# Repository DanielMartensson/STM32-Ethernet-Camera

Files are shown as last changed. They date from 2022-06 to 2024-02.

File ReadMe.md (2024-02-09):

# STM32 Ethernet camera

This project have:

 * CAN-bus
 * Encoder
 * Input capture
 * DAC 12-bit
 * ADC 12-bit
 * Digital N-channel output
 * Digital input
 * FSCM 16-Bit LCD
 * DCMI camera
 * Ethernet

This project will focus on

 * OV7670 Camera SCCB protocol for computer vision
 * Ethernet for STM32F4 series

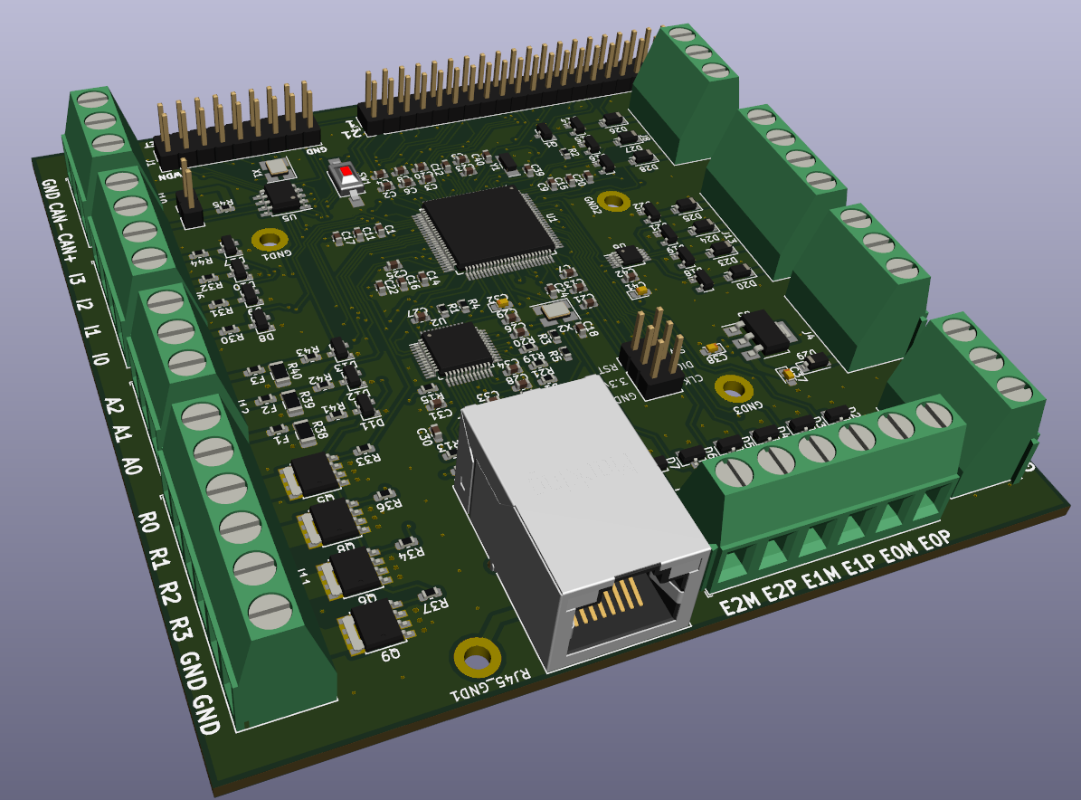
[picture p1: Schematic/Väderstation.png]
a


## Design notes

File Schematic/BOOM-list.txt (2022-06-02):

>  C1 - C42			100nF				Capacitor_SMD:C_0603_1608Metric							581-0603YC104MAT4A	29
>  C4, C8			1uF				Capacitor_SMD:C_0603_1608Metric							80-C0603C105K8R		2
    C23				4.7uF				Capacitor_SMD:C_0603_1608Metric							187-CL10A475KP8NNNC	1
>  C24, C25			2.2uF				Capacitor_SMD:C_0603_1608Metric							187-CL10A225KP8NNNC	2
>  C32 - C41			10uF				Capacitor_Tantalum_SMD:CP_EIA-1608-08_AVX-J_Pad1.25x1.05mm_HandSolder		74-TMCJ0E106MTR2F(or 755-TCSM1C106M8R)	4
>  C39, C40			4.7pF				Capacitor_SMD:C_0603_1608Metric							80-C0603C479D5HACTU	2
    D1				LED				LED_SMD:LED_0603_1608Metric							710-150060AS75000	1
>  D2 - D22			BZX84Cxx			Diode_SMD:D_SOT-23_ANK								863-BZX84C3V6LT1G	20
>  D20 - D29			D_Schottky			Diode_SMD:D_SOD-123								863-BAT54T1G		8
>  F1 - F3			Polyfuse			Resistor_SMD:R_0603_1608Metric							530-0ZCM0002FF2G	3
>  GND1 - GND3			MountingHole_Pad		MountingHole:MountingHole_2.7mm_M2.5_DIN965_Pad					~			3
    J1				Conn_02x09			Connector_PinHeader_2.54mm:PinHeader_2x09_P2.54mm_Vertical			~			1
    J2				RJ45_LED			Connector_RJ:RJ45_Wuerth_7499010121A_Horizontal					710-74990101212(or 710-7499010121A)		1
    J3				Conn_02x20			Connector_PinHeader_2.54mm:PinHeader_2x20_P2.54mm_Vertical			~			1
>  J4 - J14			Screw_Terminal_01x03		TerminalBlock_Phoenix:TerminalBlock_Phoenix_MKDS-1,5-3_1x03_P5.00mm_Horizontal	651-1935174		4
    J5				Conn_02x03			Connector_PinHeader_2.54mm:PinHeader_2x03_P2.54mm_Vertical			~			1
    J7				Conn_01x02			Connector_PinHeader_2.54mm:PinHeader_1x02_P2.54mm_Vertical			~			1
>  J9, J11			Screw_Terminal_01x06		TerminalBlock_Phoenix:TerminalBlock_Phoenix_MKDS-1,5-6_1x06_P5.00mm_Horizontal	651-1935200		2
    J10				01x03				TerminalBlock_Phoenix:TerminalBlock_Phoenix_MKDS-1,5-3_1x03_P5.00mm_Horizontal	651-1935174		1
>  J6, J13			Screw_Terminal_01x04		TerminalBlock_Phoenix:TerminalBlock_Phoenix_MKDS-1,5-4_1x04_P5.00mm_Horizontal	651-1935187		2
    Q1				BC847				Package_TO_SOT_SMD:SOT-23							863-BC847BLT1G		1
>  Q5 - Q9			BUK9Y07-30B115			Package_TO_SOT_SMD:LFPAK56							771-BUK9Y07-30B115	4
>  R1 - R43			2.2K				Resistor_SMD:R_0603_1608Metric							71-CRCW06032K20FKEAC	16
    R3				1.5K				Resistor_SMD:R_0603_1608Metric							71-CRCW06031K50FKEAC	1
    R9				4.87K				Resistor_SMD:R_0603_1608Metric							71-CRCW0603-4.87K-E3	1
>  R10 - R13			49.9				Resistor_SMD:R_0603_1608Metric							71-CRCW060349R9FKEAC	4
>  R16 - R18			110				Resistor_SMD:R_0603_1608Metric							71-CRCW0603-110-E3	3
>  R22 - R44			10K				Resistor_SMD:R_0603_1608Metric							71-CRCW060310K0JNEAC	10
>  R38 - R40			150				Resistor_SMD:R_1206_3216Metric							660-SG73P2BTTD151G	3
    R45				120				Resistor_SMD:R_0603_1608Metric							71-CRCW0603120RFKEAC	1
    RJ45_GND1			MountingHole_Pad		MountingHole:MountingHole_2.7mm_M2.5_DIN965_Pad					~			1
    SW1				SW_Push				Button_Switch_SMD:SW_SPST_FSMSM							506-FSMSM		1
    U1				STM32F407VGTx			Package_QFP:LQFP-100_14x14mm_P0.5mm						511-STM32F407VGT6	1
    U2				DP83848I			Package_QFP:LQFP-48_7x7mm_P0.5mm						926-DP83848IVV/NOPB	1
    U3				LM1117-3.3			Package_TO_SOT_SMD:SOT-223							926-LM1117MP-3.3NOPB	1
    U5				TCAN332				Package_SO:SOIC-8_3.9x4.9mm_P1.27mm						595-TCAN332DR		1
    U6				MCP4728				Package_SO:MSOP-10_3x3mm_P0.5mm							579-MCP4728A4TEUNVAO	1
    X1				24MHz				Crystal:Crystal_SMD_EuroQuartz_MT-4Pin_3.2x2.5mm_HandSoldering			520-3225MV-240-BNT(or 520-3225Q-33-240-BST)	1
    X2				50MHz				Crystal:Crystal_SMD_EuroQuartz_MT-4Pin_3.2x2.5mm_HandSoldering			520-3225MVQ-500-CN-T	1
    Y1				32.768kHz			Crystal:Crystal_SMD_MicroCrystal_CC7V-T1A-2Pin_3.2x1.5mm_HandSoldering		520-.327-12.5-34QNT(or 717-9HT1032.768KBZFT)	1

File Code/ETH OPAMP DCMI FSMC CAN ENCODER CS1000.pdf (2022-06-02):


07/02/2021

## ETH OPAMP DCMI FSMC CAN ENCODER CS1000 Project Configuration Report

# 1. Description

## 1.1. Project

Project Name | ETH OPAMP DCMI FSMC CAN ENCODER CS1000
Board Name | custom
Generated with: | STM32CubeMX 6.1.1
Date | 02/07/2021

## 1.2. MCU

MCU Series | STM32F4
MCU Line | STM32F407/417
MCU name | STM32F407VGTx
MCU Package | LQFP100
MCU Pin number | 100

## 1.3. Core(s) information

Core(s) | Arm Cortex-M4

# 2. Pinout Configuration

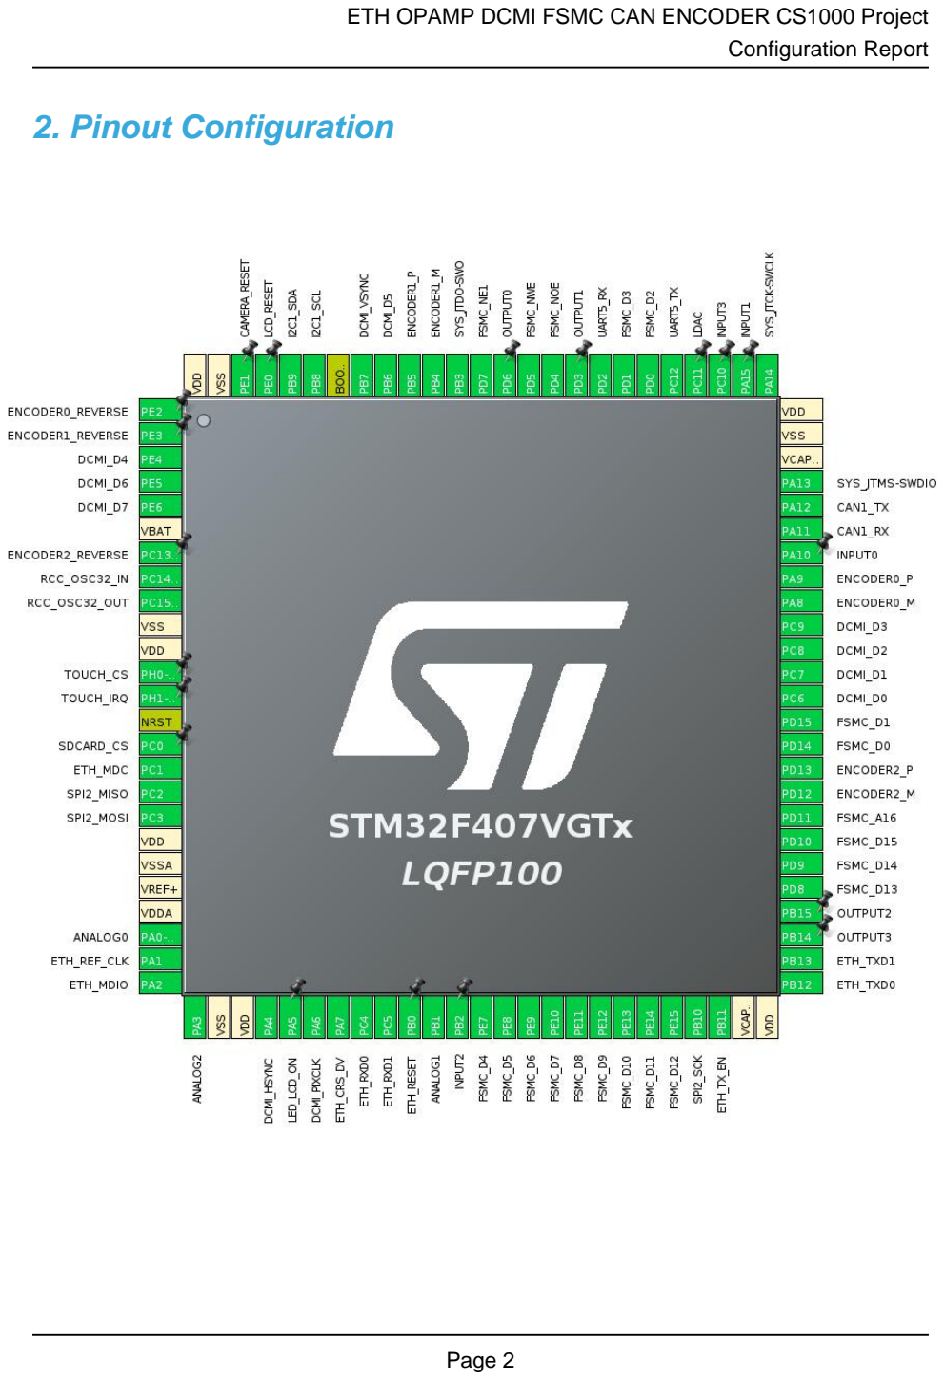
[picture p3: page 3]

# 3. Pins Configuration

Pin Number LQFP100 | Pin Name (function after reset) | Pin Type | Alternate Function(s) | Label
1 | PE2 * | I/O | GPIO_Output | ENCODER0_REVERSE
2 | PE3 * | I/O | GPIO_Output | ENCODER1_REVERSE
3 | PE4 | I/O | DCMI_D4
4 | PE5 | I/O | DCMI_D6
5 | PE6 | I/O | DCMI_D7
6 | VBAT | Power
7 | PC13-ANTI_TAMP * | I/O | GPIO_Output | ENCODER2_REVERSE
8 | PC14-OSC32_IN | I/O | RCC_OSC32_IN
9 | PC15-OSC32_OUT | I/O | RCC_OSC32_OUT
10 | VSS | Power
11 | VDD | Power
12 | PH0-OSC_IN * | I/O | GPIO_Output | TOUCH_CS
13 | PH1-OSC_OUT * | I/O | GPIO_Input | TOUCH_IRQ
14 | NRST | Reset
15 | PC0 * | I/O | GPIO_Output | SDCARD_CS
16 | PC1 | I/O | ETH_MDC
17 | PC2 | I/O | SPI2_MISO
18 | PC3 | I/O | SPI2_MOSI
19 | VDD | Power
20 | VSSA | Power
21 | VREF+ | Power
22 | VDDA | Power
23 | PA0-WKUP | I/O | ADC1_IN0 | ANALOG0
24 | PA1 | I/O | ETH_REF_CLK
25 | PA2 | I/O | ETH_MDIO
26 | PA3 | I/O | ADC1_IN3 | ANALOG2
27 | VSS | Power
28 | VDD | Power
29 | PA4 | I/O | DCMI_HSYNC
30 | PA5 * | I/O | GPIO_Output | LED_LCD_ON
31 | PA6 | I/O | DCMI_PIXCLK
32 | PA7 | I/O | ETH_CRS_DV
33 | PC4 | I/O | ETH_RXD0
34 | PC5 | I/O | ETH_RXD1
35 | PB0 * | I/O | GPIO_Output | ETH_RESET
36 | PB1 | I/O | ADC1_IN9 | ANALOG1

Pin Number LQFP100 | Pin Name (function after reset) | Pin Type | Alternate Function(s) | Label
37 | PB2 * | I/O | GPIO_Input | INPUT2
38 | PE7 | I/O | FSMC_D4
39 | PE8 | I/O | FSMC_D5
40 | PE9 | I/O | FSMC_D6
41 | PE10 | I/O | FSMC_D7
42 | PE11 | I/O | FSMC_D8
43 | PE12 | I/O | FSMC_D9
44 | PE13 | I/O | FSMC_D10
45 | PE14 | I/O | FSMC_D11
46 | PE15 | I/O | FSMC_D12
47 | PB10 | I/O | SPI2_SCK
48 | PB11 | I/O | ETH_TX_EN
49 | VCAP_1 | Power
50 | VDD | Power
51 | PB12 | I/O | ETH_TXD0
52 | PB13 | I/O | ETH_TXD1
53 | PB14 * | I/O | GPIO_Output | OUTPUT3
54 | PB15 * | I/O | GPIO_Output | OUTPUT2
55 | PD8 | I/O | FSMC_D13
56 | PD9 | I/O | FSMC_D14
57 | PD10 | I/O | FSMC_D15
58 | PD11 | I/O | FSMC_A16
59 | PD12 | I/O | TIM4_CH1 | ENCODER2_M
60 | PD13 | I/O | TIM4_CH2 | ENCODER2_P
61 | PD14 | I/O | FSMC_D0
62 | PD15 | I/O | FSMC_D1
63 | PC6 | I/O | DCMI_D0
64 | PC7 | I/O | DCMI_D1
65 | PC8 | I/O | DCMI_D2
66 | PC9 | I/O | DCMI_D3
67 | PA8 | I/O | TIM1_CH1 | ENCODER0_M
68 | PA9 | I/O | TIM1_CH2 | ENCODER0_P
69 | PA10 * | I/O | GPIO_Input | INPUT0
70 | PA11 | I/O | CAN1_RX
71 | PA12 | I/O | CAN1_TX
72 | PA13 | I/O | SYS_JTMS-SWDIO
73 | VCAP_2 | Power
74 | VSS | Power
75 | VDD | Power

Pin Number LQFP100 | Pin Name (function after reset) | Pin Type | Alternate Function(s) | Label
76 | PA14 | I/O | SYS_JTCK-SWCLK
77 | PA15 * | I/O | GPIO_Input | INPUT1
78 | PC10 * | I/O | GPIO_Input | INPUT3
79 | PC11 * | I/O | GPIO_Output | LDAC
80 | PC12 | I/O | UART5_TX
81 | PD0 | I/O | FSMC_D2
82 | PD1 | I/O | FSMC_D3
83 | PD2 | I/O | UART5_RX
84 | PD3 * | I/O | GPIO_Output | OUTPUT1
85 | PD4 | I/O | FSMC_NOE
86 | PD5 | I/O | FSMC_NWE
87 | PD6 * | I/O | GPIO_Output | OUTPUT0
88 | PD7 | I/O | FSMC_NE1
89 | PB3 | I/O | SYS_JTDO-SWO
90 | PB4 | I/O | TIM3_CH1 | ENCODER1_M
91 | PB5 | I/O | TIM3_CH2 | ENCODER1_P
92 | PB6 | I/O | DCMI_D5
93 | PB7 | I/O | DCMI_VSYNC
94 | BOOT0 | Boot
95 | PB8 | I/O | I2C1_SCL
96 | PB9 | I/O | I2C1_SDA
97 | PE0 * | I/O | GPIO_Output | LCD_RESET
98 | PE1 * | I/O | GPIO_Output | CAMERA_RESET
99 | VSS | Power
100 | VDD | Power

## * The pin is affected with an I/O function

# 4. Clock Tree Configuration

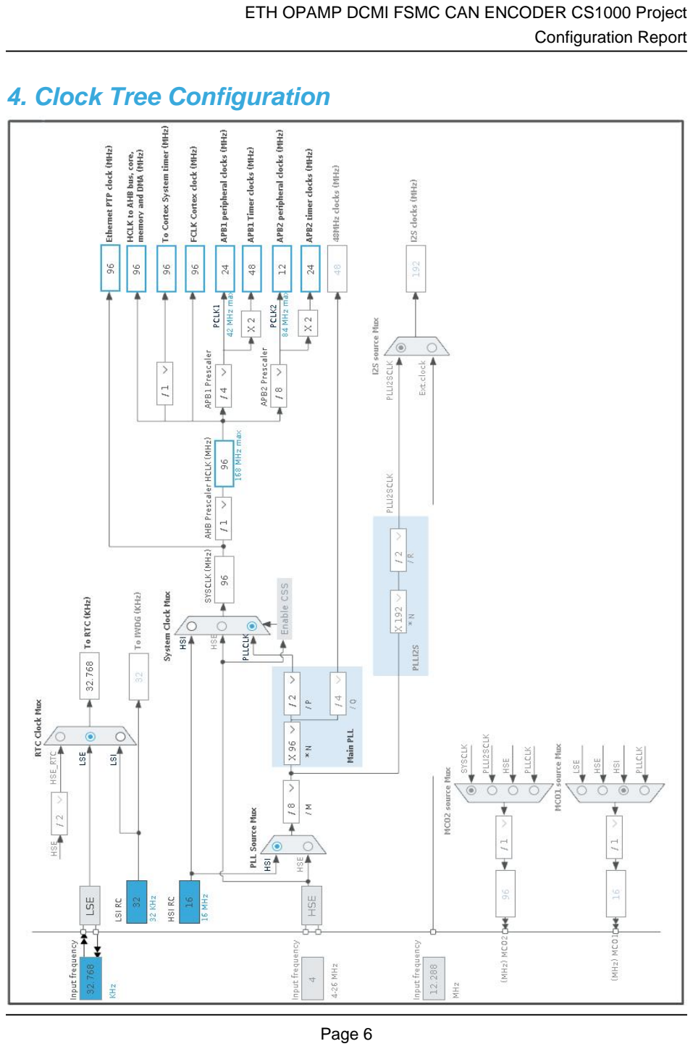
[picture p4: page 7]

# 5. Software Project

## 5.1. Project Settings

Name | Value
Project Name | ETH OPAMP DCMI FSMC CAN ENCODER CS1000
Project Folder | /home/dell/Dokument/STM32-Workspace/ETH OPAMP DCMI FSMC CAN
Toolchain / IDE | STM32CubeIDE
Firmware Package Name and Version | STM32Cube FW_F4 V1.25.2
Application Structure | Advanced
Generate Under Root | Yes
Do not generate the main() | No
Minimum Heap Size | 0x200
Minimum Stack Size | 0x400

## 5.2. Code Generation Settings

Name | Value
STM32Cube MCU packages and embedded software | Copy only the necessary library files
Generate peripheral initialization as a pair of '.c/.h' files | No
Backup previously generated files when re-generating | No
Keep User Code when re-generating | Yes
Delete previously generated files when not re-generated | Yes
Set all free pins as analog (to optimize the power consumption) | No
Enable Full Assert | No

## 5.3. Advanced Settings - Generated Function Calls

Rank | Function Name | Peripheral Instance Name
1 | MX_GPIO_Init | GPIO
2 | SystemClock_Config | RCC
3 | MX_FSMC_Init | FSMC
4 | MX_DCMI_Init | DCMI
5 | MX_I2C1_Init | I2C1
6 | MX_SPI2_Init | SPI2
7 | MX_TIM1_Init | TIM1
8 | MX_TIM3_Init | TIM3
9 | MX_ADC1_Init | ADC1
10 | MX_CAN1_Init | CAN1
11 | MX_RTC_Init | RTC

Rank | Function Name | Peripheral Instance Name
12 | MX_LWIP_Init | LWIP
13 | MX_TIM4_Init | TIM4
14 | MX_FATFS_Init | FATFS
15 | MX_UART5_Init | UART5

# 6. Power Consumption Calculator report

## 6.1. Microcontroller Selection

Series | STM32F4
Line | STM32F407/417
MCU | STM32F407VGTx
Datasheet | DS8626_Rev8

## 6.2. Parameter Selection

Temperature | 25
Vdd | 3.3

## 6.3. Battery Selection

Battery | Li-SOCL2(A3400)
Capacity | 3400.0 mAh
Self Discharge | 0.08 %/month
Nominal Voltage | 3.6 V
Max Cont Current | 100.0 mA
Max Pulse Current | 200.0 mA
Cells in series | 1
Cells in parallel | 1

## 6.4. Sequence

Step | Step1 | Step2
Mode | RUN | STOP
Vdd | 3.3 | 3.3
Voltage Source | Battery | Battery
Range | Scale1-High | No Scale
Fetch Type | FLASH | n/a
CPU Frequency | 168 MHz | 0 Hz
Clock Configuration | HSE PLL | Regulator_LP Flash-PwrDwn
Clock Source Frequency | 4 MHz | 0 Hz

### Peripherals

Additional Cons. | 0 mA | 0 mA
Average Current | 46 mA | 280 µA
Duration | 0.1 ms | 0.9 ms
DMIPS | 210.0 | 0.0
Ta Max | 98.47 | 104.96
Category | In DS Table | In DS Table

## 6.5. Results

Sequence Time | 1 ms | Average Current | 4.85 mA
Battery Life | 29 days, 4 hours | Average DMIPS | 210.0 DMIPS

## 6.6. Chart

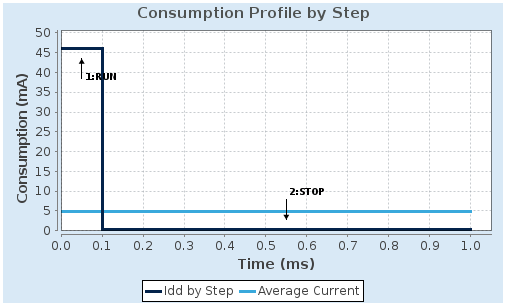
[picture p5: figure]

# 7. Peripherals and Middlewares Configuration

## 7.1. ADC1 mode: IN0 mode: IN3 mode: IN9

## 7.1.1. Parameter Settings:

### ADCs_Common_Settings:

Mode | Independent mode

### ADC_Settings:

Clock Prescaler | PCLK2 divided by 2
Resolution | 12 bits (15 ADC Clock cycles)
Data Alignment | Right alignment
Scan Conversion Mode | Disabled
Continuous Conversion Mode | Disabled
Discontinuous Conversion Mode | Disabled
DMA Continuous Requests | Disabled
End Of Conversion Selection | EOC flag at the end of single channel conversion

### ADC_Regular_ConversionMode:

Number Of Conversion | 1
External Trigger Conversion Source | Regular Conversion launched by software
External Trigger Conversion Edge | None
Rank | 1
Channel | Channel 0
Sampling Time | 3 Cycles

### ADC_Injected_ConversionMode:

Number Of Conversions | 0

### WatchDog:

Enable Analog WatchDog Mode | false

## 7.2. CAN1 mode: Activated

## 7.2.1. Parameter Settings:

### Bit Timings Parameters:

Prescaler (for Time Quantum) | 16
Time Quantum | 666.6666666666666 *

Time Quanta in Bit Segment 1 | 1 Time
Time Quanta in Bit Segment 2 | 1 Time
Time for one Bit | 1999.99 *
Baud Rate | 500000 *
ReSynchronization Jump Width | 1 Time

### Basic Parameters:

Time Triggered Communication Mode | Disable
Automatic Bus-Off Management | Disable
Automatic Wake-Up Mode | Disable
Automatic Retransmission | Disable
Receive Fifo Locked Mode | Disable
Transmit Fifo Priority | Disable

### Advanced Parameters:

Operating Mode | Normal

## 7.3. DCMI DCMI: Slave 8 bits External Synchro

## 7.3.1. Parameter Settings:

### Mode Config:

Pixel clock polarity | Active on Falling edge
Vertical synchronization polarity | Active Low
Horizontal synchronization polarity | Active Low
Frequency of frame capture | All frames are captured
JPEG mode | Disabled

## 7.4. ETH Mode: RMII

## 7.4.1. Parameter Settings:

### Advanced : Ethernet Media Configuration:

Auto Negotiation | Enabled
Speed | 100 MBits/s
Duplex Mode | Full Duplex

### General : Ethernet Configuration:

Ethernet MAC Address | 00:80:E1:00:00:00
PHY Address | 5 *

### Ethernet Basic Configuration:

Rx Mode | Interrupt Mode
TX IP Header Checksum Computation | By hardware

## 7.4.2. Advanced Parameters:

### External PHY Configuration:

PHY | DP83848_PHY_ADDRESS *
PHY Address Value | 5
PHY Reset delay these values are based on a 1 ms Systick interrupt | 0x000000FF *
PHY Configuration delay | 0x00000FFF *
PHY Read TimeOut | 0x0000FFFF *
PHY Write TimeOut | 0x0000FFFF *

### Common : External PHY Configuration:

Transceiver Basic Control Register | 0x00 *
Transceiver Basic Status Register | 0x01 *
PHY Reset | 0x8000 *
Select loop-back mode | 0x4000 *
Set the full-duplex mode at 100 Mb/s | 0x2100 *
Set the half-duplex mode at 100 Mb/s | 0x2000 *
Set the full-duplex mode at 10 Mb/s | 0x0100 *
Set the half-duplex mode at 10 Mb/s | 0x0000 *
Enable auto-negotiation function | 0x1000 *
Restart auto-negotiation function | 0x0200 *
Select the power down mode | 0x0800 *
Isolate PHY from MII | 0x0400 *
Auto-Negotiation process completed | 0x0020 *
Valid link established | 0x0004 *
Jabber condition detected | 0x0002 *

### Extended : External PHY Configuration:

PHY special control/status register Offset | 0x1F *
PHY Speed mask | 0x0004 *
PHY Duplex mask | 0x0010 *
PHY Interrupt Source Flag register Offset | 0x001D *
PHY Link down inturrupt | 0x000B *

## 7.5. FSMC

## NOR Flash/PSRAM/SRAM/ROM/LCD 1

## Chip Select: set Memory type: LCD Interface LCD Register Select: A16 Data: 16 bits

## 7.5.1. NOR/PSRAM 1:

### NOR/PSRAM control:

Memory type | LCD Interface
Bank | Bank 1 NOR/PSRAM 1
Write operation | Enabled
Extended mode | Disabled

### NOR/PSRAM timing:

Address setup time in HCLK clock cycles | 15
Data setup time in HCLK clock cycles | 255
Bus turn around time in HCLK clock cycles | 15

## 7.6. I2C1 I2C: I2C

## 7.6.1. Parameter Settings:

### Master Features:

I2C Speed Mode | Standard Mode
I2C Clock Speed (Hz) | 100000

### Slave Features:

Clock No Stretch Mode | Disabled
Primary Address Length selection | 7-bit
Dual Address Acknowledged | Disabled
Primary slave address | 0
General Call address detection | Disabled

## 7.7. RCC

## Low Speed Clock (LSE) : Crystal/Ceramic Resonator

## 7.7.1. Parameter Settings:

### System Parameters:

VDD voltage (V) | 3.3
Instruction Cache | Enabled
Prefetch Buffer | Enabled
Data Cache | Enabled
Flash Latency(WS) | 3 WS (4 CPU cycle)

### RCC Parameters:

HSI Calibration Value | 16
HSE Startup Timout Value (ms) | 100
LSE Startup Timout Value (ms) | 5000

### Power Parameters:

Power Regulator Voltage Scale | Power Regulator Voltage Scale 1

## 7.8. RTC mode: Activate Clock Source

## 7.8.1. Parameter Settings:

### General:

Hour Format | Hourformat 24
Asynchronous Predivider value | 127
Synchronous Predivider value | 255

## 7.9. SPI2 Mode: Full-Duplex Master

## 7.9.1. Parameter Settings:

### Basic Parameters:

Frame Format | Motorola
Data Size | 8 Bits
First Bit | MSB First

### Clock Parameters:

Prescaler (for Baud Rate) | 2
Baud Rate | 12.0 MBits/s *
Clock Polarity (CPOL) | Low

Clock Phase (CPHA) | 1 Edge

### Advanced Parameters:

CRC Calculation | Disabled
NSS Signal Type | Software

## 7.10. SYS Debug: Trace Asynchronous Sw Timebase Source: TIM2

## 7.11. TIM1 Combined Channels: Encoder Mode

## 7.11.1. Parameter Settings:

### Counter Settings:

Prescaler (PSC - 16 bits value) | 0
Counter Mode | Up
Counter Period (AutoReload Register - 16 bits value ) | 65535
Internal Clock Division (CKD) | No Division
Repetition Counter (RCR - 8 bits value) | 0
auto-reload preload | Disable

### Trigger Output (TRGO) Parameters:

Master/Slave Mode (MSM bit) | Disable (Trigger input effect not delayed)
Trigger Event Selection | Reset (UG bit from TIMx_EGR)

### Encoder:

Encoder Mode | Encoder Mode TI1
____ Parameters for Channel 1 ____
Polarity | Rising Edge
IC Selection | Direct
Prescaler Division Ratio | No division
Input Filter | 0
____ Parameters for Channel 2 ____
Polarity | Rising Edge
IC Selection | Direct
Prescaler Division Ratio | No division
Input Filter | 0

## 7.12. TIM3 Combined Channels: Encoder Mode

## 7.12.1. Parameter Settings:

### Counter Settings:

Prescaler (PSC - 16 bits value) | 0
Counter Mode | Up
Counter Period (AutoReload Register - 16 bits value ) | 65535
Internal Clock Division (CKD) | No Division
auto-reload preload | Disable

### Trigger Output (TRGO) Parameters:

Master/Slave Mode (MSM bit) | Disable (Trigger input effect not delayed)
Trigger Event Selection | Reset (UG bit from TIMx_EGR)

### Encoder:

Encoder Mode | Encoder Mode TI1
____ Parameters for Channel 1 ____
Polarity | Rising Edge
IC Selection | Direct
Prescaler Division Ratio | No division
Input Filter | 0
____ Parameters for Channel 2 ____
Polarity | Rising Edge
IC Selection | Direct
Prescaler Division Ratio | No division
Input Filter | 0

## 7.13. TIM4 Combined Channels: Encoder Mode

## 7.13.1. Parameter Settings:

### Counter Settings:

Prescaler (PSC - 16 bits value) | 0
Counter Mode | Up
Counter Period (AutoReload Register - 16 bits value ) | 65535
Internal Clock Division (CKD) | No Division
auto-reload preload | Disable

### Trigger Output (TRGO) Parameters:

Master/Slave Mode (MSM bit) | Disable (Trigger input effect not delayed)
Trigger Event Selection | Reset (UG bit from TIMx_EGR)

### Encoder:

Encoder Mode | Encoder Mode TI1
____ Parameters for Channel 1 ____
Polarity | Rising Edge
IC Selection | Direct
Prescaler Division Ratio | No division
Input Filter | 0
____ Parameters for Channel 2 ____
Polarity | Rising Edge
IC Selection | Direct
Prescaler Division Ratio | No division
Input Filter | 0

## 7.14. UART5 Mode: Asynchronous

## 7.14.1. Parameter Settings:

### Basic Parameters:

Baud Rate | 115200
Word Length | 8 Bits (including Parity)
Parity | None
Stop Bits | 1

### Advanced Parameters:

Data Direction | Receive and Transmit
Over Sampling | 16 Samples

## 7.15. FATFS mode: User-defined

## 7.15.1. Set Defines:

### Version:

FATFS version | R0.12c

### Function Parameters:

FS_READONLY (Read-only mode) | Disabled
FS_MINIMIZE (Minimization level) | Disabled
USE_STRFUNC (String functions) | Enabled with LF -> CRLF conversion
USE_FIND (Find functions) | Disabled
USE_MKFS (Make filesystem function) | Enabled

USE_FASTSEEK (Fast seek function) | Enabled
USE_EXPAND (Use f_expand function) | Disabled
USE_CHMOD (Change attributes function) | Disabled
USE_LABEL (Volume label functions) | Disabled
USE_FORWARD (Forward function) | Disabled

### Locale and Namespace Parameters:

CODE_PAGE (Code page on target) | Latin 1
USE_LFN (Use Long Filename) | Disabled
MAX_LFN (Max Long Filename) | 255
LFN_UNICODE (Enable Unicode) | ANSI/OEM
STRF_ENCODE (Character encoding) | UTF-8
FS_RPATH (Relative Path) | Disabled

### Physical Drive Parameters:

VOLUMES (Logical drives) | 1
MAX_SS (Maximum Sector Size) | 512
MIN_SS (Minimum Sector Size) | 512
MULTI_PARTITION (Volume partitions feature) | Disabled
USE_TRIM (Erase feature) | Disabled
FS_NOFSINFO (Force full FAT scan) | 0

### System Parameters:

FS_TINY (Tiny mode) | Disabled
FS_EXFAT (Support of exFAT file system) | Disabled
FS_NORTC (Timestamp feature) | Dynamic timestamp
FS_REENTRANT (Re-Entrancy) | Enabled
FS_TIMEOUT (Timeout ticks) | 1000
USE_MUTEX | Disabled
SYNC_t (O/S sync object) | osSemaphoreId_t
FS_LOCK (Number of files opened simultaneously) | 2

## 7.16. FREERTOS Interface: CMSIS_V2

## 7.16.1. Config parameters:

### API:

FreeRTOS API | CMSIS v2

### Versions:

FreeRTOS version | 10.2.1
CMSIS-RTOS version | 2.00

### MPU/FPU:

ENABLE_MPU | Disabled

ENABLE_FPU | Disabled

### Kernel settings:

USE_PREEMPTION | Enabled
CPU_CLOCK_HZ | SystemCoreClock
TICK_RATE_HZ | 1000
MAX_PRIORITIES | 56
MINIMAL_STACK_SIZE | 128
MAX_TASK_NAME_LEN | 16
USE_16_BIT_TICKS | Disabled
IDLE_SHOULD_YIELD | Enabled
USE_MUTEXES | Enabled
USE_RECURSIVE_MUTEXES | Enabled
USE_COUNTING_SEMAPHORES | Enabled
QUEUE_REGISTRY_SIZE | 8
USE_APPLICATION_TASK_TAG | Disabled
ENABLE_BACKWARD_COMPATIBILITY | Enabled
USE_PORT_OPTIMISED_TASK_SELECTION | Disabled
USE_TICKLESS_IDLE | Disabled
USE_TASK_NOTIFICATIONS | Enabled
RECORD_STACK_HIGH_ADDRESS | Disabled

### Memory management settings:

Memory Allocation | Dynamic / Static
TOTAL_HEAP_SIZE | 15360
Memory Management scheme | heap_4

### Hook function related definitions:

USE_IDLE_HOOK | Disabled
USE_TICK_HOOK | Disabled
USE_MALLOC_FAILED_HOOK | Disabled
USE_DAEMON_TASK_STARTUP_HOOK | Disabled
CHECK_FOR_STACK_OVERFLOW | Disabled

### Run time and task stats gathering related definitions:

GENERATE_RUN_TIME_STATS | Disabled
USE_TRACE_FACILITY | Enabled
USE_STATS_FORMATTING_FUNCTIONS | Disabled

### Co-routine related definitions:

USE_CO_ROUTINES | Disabled
MAX_CO_ROUTINE_PRIORITIES | 2

### Software timer definitions:

USE_TIMERS | Enabled
TIMER_TASK_PRIORITY | 2
TIMER_QUEUE_LENGTH | 10
TIMER_TASK_STACK_DEPTH | 256

### Interrupt nesting behaviour configuration:

LIBRARY_LOWEST_INTERRUPT_PRIORITY | 15
LIBRARY_MAX_SYSCALL_INTERRUPT_PRIORITY | 5

### Added with 10.2.1 support:

MESSAGE_BUFFER_LENGTH_TYPE | size_t
USE_POSIX_ERRNO | Disabled

## 7.16.2. Include parameters:

### Include definitions:

vTaskPrioritySet | Enabled
uxTaskPriorityGet | Enabled
vTaskDelete | Enabled
vTaskCleanUpResources | Disabled
vTaskSuspend | Enabled
vTaskDelayUntil | Enabled
vTaskDelay | Enabled
xTaskGetSchedulerState | Enabled
xTaskResumeFromISR | Enabled
xQueueGetMutexHolder | Enabled
xSemaphoreGetMutexHolder | Disabled
pcTaskGetTaskName | Disabled
uxTaskGetStackHighWaterMark | Enabled
xTaskGetCurrentTaskHandle | Disabled
eTaskGetState | Enabled
xEventGroupSetBitFromISR | Disabled
xTimerPendFunctionCall | Enabled
xTaskAbortDelay | Disabled
xTaskGetHandle | Disabled
uxTaskGetStackHighWaterMark2 | Disabled

## 7.16.3. Advanced settings:

### Newlib settings (see parameter description first):

USE_NEWLIB_REENTRANT | Disabled

### Project settings (see parameter description first):

Use FW pack heap file | Enabled

## 7.17. LWIP mode: Enabled

Advanced parameters are not listed except if modified by user.

## 7.17.1. General Settings:

### LwIP Version:

LwIP Version (Version of LwIP supported by CubeMX ** CubeMX specific **) | 2.1.2

### IPv4 - DHCP Options:

LWIP_DHCP (DHCP Module) | Enabled

### RTOS Dependency:

WITH_RTOS (Use FREERTOS ** CubeMX specific **) | Enabled
CMSIS_VERSION (CMSIS API Version used) | CMSIS v2

### Protocols Options:

LWIP_ICMP (ICMP Module Activation) | Enabled
LWIP_IGMP (IGMP Module) | Disabled
LWIP_DNS (DNS Module) | Disabled
LWIP_UDP (UDP Module) | Enabled
MEMP_NUM_UDP_PCB (Number of UDP Connections) | 4
LWIP_TCP (TCP Module) | Enabled
MEMP_NUM_TCP_PCB (Number of TCP Connections) | 5

## 7.17.2. Key Options:

### Infrastructure - OS Awarness Option:

NO_SYS (OS Awarness) | OS Used

### Infrastructure - Timers Options:

LWIP_TIMERS (Use Support For sys_timeout) | Enabled

### Infrastructure - Core Locking and MPU Options:

SYS_LIGHTWEIGHT_PROT (Memory Functions Protection) | Enabled

### Infrastructure - Heap and Memory Pools Options:

MEM_SIZE (Heap Memory Size) | 1600

### Infrastructure - Internal Memory Pool Sizes:

MEMP_NUM_PBUF (Number of Memory Pool struct Pbufs) | 16
MEMP_NUM_RAW_PCB (Number of Raw Protocol Control Blocks) | 4
MEMP_NUM_TCP_PCB_LISTEN (Number of Listening TCP Connections) | 8
MEMP_NUM_TCP_SEG (Number of TCP Segments simultaneously queued) | 16
MEMP_NUM_LOCALHOSTLIST (Number of Host Entries in the Local Host List) | 1

### Pbuf Options:

PBUF_POOL_SIZE (Number of Buffers in the Pbuf Pool) | 16

PBUF_POOL_BUFSIZE (Size of each pbuf in the pbuf pool) | 592

### IPv4 - ARP Options:

LWIP_ARP (ARP Functionality) | Enabled

### Callback - TCP Options:

TCP_TTL (Number of Time-To-Live Used by TCP Packets) | 255
TCP_WND (TCP Receive Window Maximum Size) | 2144
TCP_QUEUE_OOSEQ (Allow Out-Of-Order Incoming Packets) | Enabled
LWIP_TCP_SACK_OUT (Allow Sending Selective Acknowledgements) | Disabled
TCP_MSS (Maximum Segment Size) | 536
TCP_SND_BUF (TCP Sender Buffer Space) | 1072
TCP_SND_QUEUELEN (Number of Packet Buffers Allowed for TCP Sender) | 9

### Network Interfaces Options:

LWIP_NETIF_STATUS_CALLBACK (Callback Function on Interface Status Changes) | Disabled
LWIP_NETIF_EXT_STATUS_CALLBACK (Extended Callback Function for several netif) | Disabled
LWIP_NETIF_LINK_CALLBACK (Callback Function on Interface Link Changes) | Enabled

### NETIF - Loopback Interface Options:

LWIP_NETIF_LOOPBACK (NETIF Loopback) | Disabled

### Infrastructure - Threading Options:

TCPIP_THREAD_NAME (TCPIP Thread Name) | "tcpip_thread"
TCPIP_THREAD_STACKSIZE (TCPIP Thread Stack Size) | 1024
TCPIP_THREAD_PRIO (TCPIP Thread Priority Level) | 24
TCPIP_MBOX_SIZE (TCPIP Mailbox Size) | 6
DEFAULT_THREAD_NAME (Default LwIP Thread Name) | "lwIP"
DEFAULT_THREAD_STACKSIZE (Default LwIP Thread Stack Size) | 1024
DEFAULT_THREAD_PRIO (Default LwIP Thread Priority Level) | 3
DEFAULT_RAW_RECVMBOX_SIZE (Default Mailbox Size on a NETCONN Raw) | 0
DEFAULT_TCP_RECVMBOX_SIZE (Default Mailbox Size on a NETCONN TCP) | 6
DEFAULT_ACCEPTMBOX_SIZE (Default Mailbox Size for Incoming Connections) | 6

### Thread Safe APIs - Netconn Options:

LWIP_NETCONN (NETCONN API) | Enabled

### Thread Safe APIs - Socket Options:

LWIP_SOCKET (Socket API) | Enabled
LWIP_COMPAT_SOCKETS (BSD-style Socket Functions Names) | 1
LWIP_SOCKET_OFFSET (Socket Offset Number) | 0
LWIP_SOCKET_SELECT (Select for Socket) | Enabled
LWIP_SOCKET_POLL (Poll for Socket) | Enabled

## 7.17.3. PPP:

### PPP Options:

PPP_SUPPORT (PPP Module) | Disabled

## 7.17.4. IPv6:

### IPv6 Options:

LWIP_IPV6 (IPv6 Protocol) | Disabled

## 7.17.5. HTTPD:

### HTTPD Options:

LWIP_HTTPD (LwIP HTTPD Support ** CubeMX specific **) | Disabled

## 7.17.6. SNMP:

### SNMP Options:

LWIP_SNMP (LwIP SNMP Agent) | Disabled

## 7.17.7. SNTP/SMTP:

### SNTP Options:

LWIP_SNTP (LWIP SNTP Support ** CubeMX specific **) | Disabled

### SMTP Options:

LWIP_SMTP (LWIP SMTP Support ** CubeMX specific **) | Disabled

## 7.17.8. MDNS/TFTP:

### MDNS Options:

LWIP_MDNS (Multicast DNS Support ** CubeMX specific **) | Disabled

### TFTP Options:

LWIP_TFTP (TFTP Support ** CubeMX specific **) | Disabled

## 7.17.9. Perf/Checks:

### Sanity Checks:

LWIP_DISABLE_TCP_SANITY_CHECKS (TCP Sanity Checks) | Disabled
LWIP_DISABLE_MEMP_SANITY_CHECKS (MEMP Sanity Checks) | Disabled

### Performance Options:

LWIP_PERF (Performace Testing for LwIP) | Disabled

## 7.17.10. Statistics:

### Debug - Statistics Options:

LWIP_STATS (Statictics Collection) | Disabled

## 7.17.11. Checksum:

### Infrastructure - Checksum Options:

CHECKSUM_BY_HARDWARE (Hardware Checksum ** CubeMX specific **) | Enabled
LWIP_CHECKSUM_CTRL_PER_NETIF (Generate/Check Checksum per Netif) | Disabled
CHECKSUM_GEN_IP (Generate Software Checksum for Outgoing IP Packets) | Disabled
CHECKSUM_GEN_UDP (Generate Software Checksum for Outgoing UDP Packets) | Disabled
CHECKSUM_GEN_TCP (Generate Software Checksum for Outgoing TCP Packets) | Disabled
CHECKSUM_GEN_ICMP (Generate Software Checksum for Outgoing ICMP Packets) | Disabled
CHECKSUM_GEN_ICMP6 (Generate Software Checksum for Outgoing ICMP6 Packets) | Disabled
CHECKSUM_CHECK_IP (Generate Software Checksum for Incoming IP Packets) | Disabled
CHECKSUM_CHECK_UDP (Generate Software Checksum for Incoming UDP Packets) | Disabled
CHECKSUM_CHECK_TCP (Generate Software Checksum for Incoming TCP Packets) | Disabled
CHECKSUM_CHECK_ICMP (Generate Software Checksum for Incoming ICMP Packets) | Disabled
CHECKSUM_CHECK_ICMP6 (Generate Software Checksum for Incoming ICMP6 Packets) | Disabled

## 7.17.12. Debug:

### LwIP Main Debugging Options:

LWIP_DBG_MIN_LEVEL (Minimum Level) | All

### * User modified value

# 8. System Configuration

## 8.1. GPIO configuration

IP | Pin | Signal | GPIO mode | GPIO pull/up pull down

## Max Speed

## User Label

ADC1 | PA0-WKUP | ADC1_IN0 | Analog mode | No pull-up and no pull-down | n/a | ANALOG0
| PA3 | ADC1_IN3 | Analog mode | No pull-up and no pull-down | n/a | ANALOG2
| PB1 | ADC1_IN9 | Analog mode | No pull-up and no pull-down | n/a | ANALOG1
CAN1 | PA11 | CAN1_RX | Alternate Function Push Pull | No pull-up and no pull-down | Very High
*
| PA12 | CAN1_TX | Alternate Function Push Pull | No pull-up and no pull-down | Very High
*
DCMI | PE4 | DCMI_D4 | Alternate Function Push Pull | No pull-up and no pull-down | Low
| PE5 | DCMI_D6 | Alternate Function Push Pull | No pull-up and no pull-down | Low
| PE6 | DCMI_D7 | Alternate Function Push Pull | No pull-up and no pull-down | Low
PA4 | DCMI_HSYNC Alternate Function Push Pull | No pull-up and no pull-down | Low
PA6 | DCMI_PIXCLK Alternate Function Push Pull | No pull-up and no pull-down | Low
| PC6 | DCMI_D0 | Alternate Function Push Pull | No pull-up and no pull-down | Low
| PC7 | DCMI_D1 | Alternate Function Push Pull | No pull-up and no pull-down | Low
| PC8 | DCMI_D2 | Alternate Function Push Pull | No pull-up and no pull-down | Low
| PC9 | DCMI_D3 | Alternate Function Push Pull | No pull-up and no pull-down | Low
| PB6 | DCMI_D5 | Alternate Function Push Pull | No pull-up and no pull-down | Low
PB7 | DCMI_VSYNC Alternate Function Push Pull | No pull-up and no pull-down | Low
ETH | PC1 | ETH_MDC | Alternate Function Push Pull | No pull-up and no pull-down | Very High
*
PA1 | ETH_REF_CLK Alternate Function Push Pull | No pull-up and no pull-down | Very High
*
| PA2 | ETH_MDIO | Alternate Function Push Pull | No pull-up and no pull-down | Very High
*
PA7 | ETH_CRS_DV Alternate Function Push Pull | No pull-up and no pull-down | Very High
*
| PC4 | ETH_RXD0 | Alternate Function Push Pull | No pull-up and no pull-down | Very High
*
| PC5 | ETH_RXD1 | Alternate Function Push Pull | No pull-up and no pull-down | Very High
*
| PB11 | ETH_TX_EN | Alternate Function Push Pull | No pull-up and no pull-down | Very High
*
| PB12 | ETH_TXD0 | Alternate Function Push Pull | No pull-up and no pull-down | Very High
*

IP | Pin | Signal | GPIO mode | GPIO pull/up pull down

## Max Speed

## User Label

| PB13 | ETH_TXD1 | Alternate Function Push Pull | No pull-up and no pull-down | Very High
*
FSMC | PE7 | FSMC_D4 | Alternate Function Push Pull | No pull-up and no pull-down | Very High
| PE8 | FSMC_D5 | Alternate Function Push Pull | No pull-up and no pull-down | Very High
| PE9 | FSMC_D6 | Alternate Function Push Pull | No pull-up and no pull-down | Very High
| PE10 | FSMC_D7 | Alternate Function Push Pull | No pull-up and no pull-down | Very High
| PE11 | FSMC_D8 | Alternate Function Push Pull | No pull-up and no pull-down | Very High
| PE12 | FSMC_D9 | Alternate Function Push Pull | No pull-up and no pull-down | Very High
| PE13 | FSMC_D10 | Alternate Function Push Pull | No pull-up and no pull-down | Very High
| PE14 | FSMC_D11 | Alternate Function Push Pull | No pull-up and no pull-down | Very High
| PE15 | FSMC_D12 | Alternate Function Push Pull | No pull-up and no pull-down | Very High
| PD8 | FSMC_D13 | Alternate Function Push Pull | No pull-up and no pull-down | Very High
| PD9 | FSMC_D14 | Alternate Function Push Pull | No pull-up and no pull-down | Very High
| PD10 | FSMC_D15 | Alternate Function Push Pull | No pull-up and no pull-down | Very High
| PD11 | FSMC_A16 | Alternate Function Push Pull | No pull-up and no pull-down | Very High
| PD14 | FSMC_D0 | Alternate Function Push Pull | No pull-up and no pull-down | Very High
| PD15 | FSMC_D1 | Alternate Function Push Pull | No pull-up and no pull-down | Very High
| PD0 | FSMC_D2 | Alternate Function Push Pull | No pull-up and no pull-down | Very High
| PD1 | FSMC_D3 | Alternate Function Push Pull | No pull-up and no pull-down | Very High
| PD4 | FSMC_NOE | Alternate Function Push Pull | No pull-up and no pull-down | Very High
| PD5 | FSMC_NWE | Alternate Function Push Pull | No pull-up and no pull-down | Very High
| PD7 | FSMC_NE1 | Alternate Function Push Pull | No pull-up and no pull-down | Very High
I2C1 | PB8 | I2C1_SCL | Alternate Function Open Drain | Pull-up | Very High
*
| PB9 | I2C1_SDA | Alternate Function Open Drain | Pull-up | Very High
*
RCC | PC14- OSC32_IN | RCC_OSC32_IN | n/a | n/a | n/a
| PC15- OSC32_OU T | RCC_OSC32_O UT | n/a | n/a | n/a
SPI2 | PC2 | SPI2_MISO | Alternate Function Push Pull | No pull-up and no pull-down | Very High
*
| PC3 | SPI2_MOSI | Alternate Function Push Pull | No pull-up and no pull-down | Very High
*
| PB10 | SPI2_SCK | Alternate Function Push Pull | No pull-up and no pull-down | Very High
*
SYS | PA13 | SYS_JTMS- SWDIO | n/a | n/a | n/a
| PA14 | SYS_JTCK- | n/a | n/a | n/a

IP | Pin | Signal | GPIO mode | GPIO pull/up pull down | Max Speed | User Label
| | SWCLK
| PB3 | SYS_JTDO-SWO | n/a | n/a | n/a
TIM1 | PA8 | TIM1_CH1 | Alternate Function Push Pull | No pull-up and no pull-down | Low | ENCODER0_M
| PA9 | TIM1_CH2 | Alternate Function Push Pull | No pull-up and no pull-down | Low | ENCODER0_P
TIM3 | PB4 | TIM3_CH1 | Alternate Function Push Pull | No pull-up and no pull-down | Low | ENCODER1_M
| PB5 | TIM3_CH2 | Alternate Function Push Pull | No pull-up and no pull-down | Low | ENCODER1_P
TIM4 | PD12 | TIM4_CH1 | Alternate Function Push Pull | No pull-up and no pull-down | Low | ENCODER2_M
| PD13 | TIM4_CH2 | Alternate Function Push Pull | No pull-up and no pull-down | Low | ENCODER2_P
UART5 | PC12 | UART5_TX | Alternate Function Push Pull | Pull-up | Very High *
| PD2 | UART5_RX | Alternate Function Push Pull | Pull-up | Very High *
GPIO | PE2 | GPIO_Output | Output Push Pull | No pull-up and no pull-down | Low | ENCODER0_REVERSE
PE3 | GPIO_Output | Output Push Pull | No pull-up and no pull-down | Low | ENCODER1_REVERSE
PC13-ANTI_TAMP | GPIO_Output | Output Push Pull | No pull-up and no pull-down | Low | ENCODER2_REVERSE
PH0-OSC_IN | GPIO_Output | Output Push Pull | No pull-up and no pull-down | Low | TOUCH_CS
PH1-OSC_OUT | GPIO_Input | Input mode | No pull-up and no pull-down | n/a | TOUCH_IRQ
PC0 | GPIO_Output | Output Push Pull | No pull-up and no pull-down | Low | SDCARD_CS
PA5 | GPIO_Output | Output Push Pull | No pull-up and no pull-down | Low | LED_LCD_ON
PB0 | GPIO_Output | Output Push Pull | No pull-up and no pull-down | Low | ETH_RESET
PB2 | GPIO_Input | Input mode | No pull-up and no pull-down | n/a | INPUT2
PB14 | GPIO_Output | Output Push Pull | No pull-up and no pull-down | Low | OUTPUT3
PB15 | GPIO_Output | Output Push Pull | No pull-up and no pull-down | Low | OUTPUT2
PA10 | GPIO_Input | Input mode | No pull-up and no pull-down | n/a | INPUT0
PA15 | GPIO_Input | Input mode | No pull-up and no pull-down | n/a | INPUT1
PC10 | GPIO_Input | Input mode | No pull-up and no pull-down | n/a | INPUT3
PC11 | GPIO_Output | Output Push Pull | No pull-up and no pull-down | Low | LDAC
PD3 | GPIO_Output | Output Push Pull | No pull-up and no pull-down | Low | OUTPUT1
PD6 | GPIO_Output | Output Push Pull | No pull-up and no pull-down | Low | OUTPUT0
PE0 | GPIO_Output | Output Push Pull | No pull-up and no pull-down | Low | LCD_RESET
PE1 | GPIO_Output | Output Push Pull | No pull-up and no pull-down | Low | CAMERA_RESET

## 8.2. DMA configuration

## nothing configured in DMA service

## 8.3. NVIC configuration

## 8.3.1. NVIC

Interrupt Table | Enable | Preenmption Priority | SubPriority
Non maskable interrupt | true | 0 | 0
Hard fault interrupt | true | 0 | 0
Memory management fault | true | 0 | 0
Pre-fetch fault, memory access fault | true | 0 | 0
Undefined instruction or illegal state | true | 0 | 0
System service call via SWI instruction | true | 0 | 0
Debug monitor | true | 0 | 0
Pendable request for system service | true | 15 | 0
System tick timer | true | 15 | 0
TIM2 global interrupt | true | 0 | 0
Ethernet global interrupt | true | 5 | 0
PVD interrupt through EXTI line 16 | | unused
Flash global interrupt | | unused
RCC global interrupt | | unused
ADC1, ADC2 and ADC3 global interrupts | | unused
CAN1 TX interrupts | | unused
CAN1 RX0 interrupts | | unused
CAN1 RX1 interrupt | | unused
CAN1 SCE interrupt | | unused
TIM1 break interrupt and TIM9 global interrupt | | unused
TIM1 update interrupt and TIM10 global interrupt | | unused
TIM1 trigger and commutation interrupts and TIM11 global interrupt | | unused
TIM1 capture compare interrupt | | unused
TIM3 global interrupt | | unused
TIM4 global interrupt | | unused
I2C1 event interrupt | | unused
I2C1 error interrupt | | unused
SPI2 global interrupt | | unused
UART5 global interrupt | | unused
Ethernet wake-up interrupt through EXTI line 19 | | unused
DCMI global interrupt | | unused
FPU global interrupt | | unused

## 8.3.2. NVIC Code generation

Enabled interrupt Table | Select for init | Generate IRQ | Call HAL handler

Enabled interrupt Table | Select for init sequence ordering | Generate IRQ handler | Call HAL handler
Non maskable interrupt | false | true | false
Hard fault interrupt | false | true | false
Memory management fault | false | true | false
Pre-fetch fault, memory access fault | false | true | false
Undefined instruction or illegal state | false | true | false
System service call via SWI instruction | false | false | false
Debug monitor | false | true | false
Pendable request for system service | false | false | false
System tick timer | false | false | true
TIM2 global interrupt | false | true | true
Ethernet global interrupt | false | true | true

### * User modified value

# 9. System Views

## 9.1. Category view 9.1.1. Current

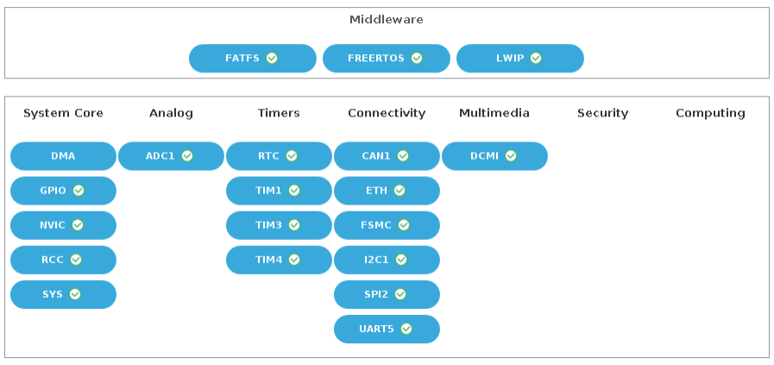
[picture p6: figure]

# 10. Docs & Resources

Type | Link
Datasheet | http://www.st.com/resource/en/datasheet/DM00037051.pdf
Reference manual | http://www.st.com/resource/en/reference_manual/DM00031020.pdf
Programming manual | http://www.st.com/resource/en/programming_manual/DM00046982.pdf
Errata sheet | http://www.st.com/resource/en/errata_sheet/DM00037591.pdf
Application note | http://www.st.com/resource/en/application_note/CD00167594.pdf
Application note | http://www.st.com/resource/en/application_note/CD00211314.pdf
Application note | http://www.st.com/resource/en/application_note/CD00249778.pdf
Application note | http://www.st.com/resource/en/application_note/CD00259245.pdf
Application note | http://www.st.com/resource/en/application_note/CD00264321.pdf
Application note | http://www.st.com/resource/en/application_note/CD00264342.pdf
Application note | http://www.st.com/resource/en/application_note/CD00264379.pdf
Application note | http://www.st.com/resource/en/application_note/DM00024853.pdf
Application note | http://www.st.com/resource/en/application_note/DM00025071.pdf
Application note | http://www.st.com/resource/en/application_note/DM00040802.pdf
Application note | http://www.st.com/resource/en/application_note/DM00040808.pdf
Application note | http://www.st.com/resource/en/application_note/DM00042534.pdf
Application note | http://www.st.com/resource/en/application_note/DM00046011.pdf
Application note | http://www.st.com/resource/en/application_note/DM00050879.pdf
Application note | http://www.st.com/resource/en/application_note/DM00072315.pdf
Application note | http://www.st.com/resource/en/application_note/DM00073742.pdf
Application note | http://www.st.com/resource/en/application_note/DM00073853.pdf
Application note | http://www.st.com/resource/en/application_note/DM00080497.pdf
Application note | http://www.st.com/resource/en/application_note/DM00081379.pdf
Application note | http://www.st.com/resource/en/application_note/DM00115714.pdf
Application note | http://www.st.com/resource/en/application_note/DM00123028.pdf

Application note | http://www.st.com/resource/en/application_note/DM00129215.pdf
Application note | http://www.st.com/resource/en/application_note/DM00154959.pdf
Application note | http://www.st.com/resource/en/application_note/DM00160482.pdf
Application note | http://www.st.com/resource/en/application_note/DM00213525.pdf
Application note | http://www.st.com/resource/en/application_note/DM00220769.pdf
Application note | http://www.st.com/resource/en/application_note/DM00257177.pdf
Application note | http://www.st.com/resource/en/application_note/DM00272912.pdf
Application note | http://www.st.com/resource/en/application_note/DM00226326.pdf
Application note | http://www.st.com/resource/en/application_note/DM00236305.pdf
Application note | http://www.st.com/resource/en/application_note/DM00263732.pdf
Application note | http://www.st.com/resource/en/application_note/DM00281138.pdf
Application note | http://www.st.com/resource/en/application_note/DM00296349.pdf
Application note | http://www.st.com/resource/en/application_note/DM00327191.pdf
Application note | http://www.st.com/resource/en/application_note/DM00354244.pdf
Application note | http://www.st.com/resource/en/application_note/DM00373474.pdf
Application note | http://www.st.com/resource/en/application_note/DM00315319.pdf
Application note | http://www.st.com/resource/en/application_note/DM00380469.pdf
Application note | http://www.st.com/resource/en/application_note/DM00395696.pdf
Application note | http://www.st.com/resource/en/application_note/DM00431633.pdf
Application note | http://www.st.com/resource/en/application_note/DM00493651.pdf
Application note | http://www.st.com/resource/en/application_note/DM00536349.pdf
Application note | http://www.st.com/resource/en/application_note/DM00725181.pdf

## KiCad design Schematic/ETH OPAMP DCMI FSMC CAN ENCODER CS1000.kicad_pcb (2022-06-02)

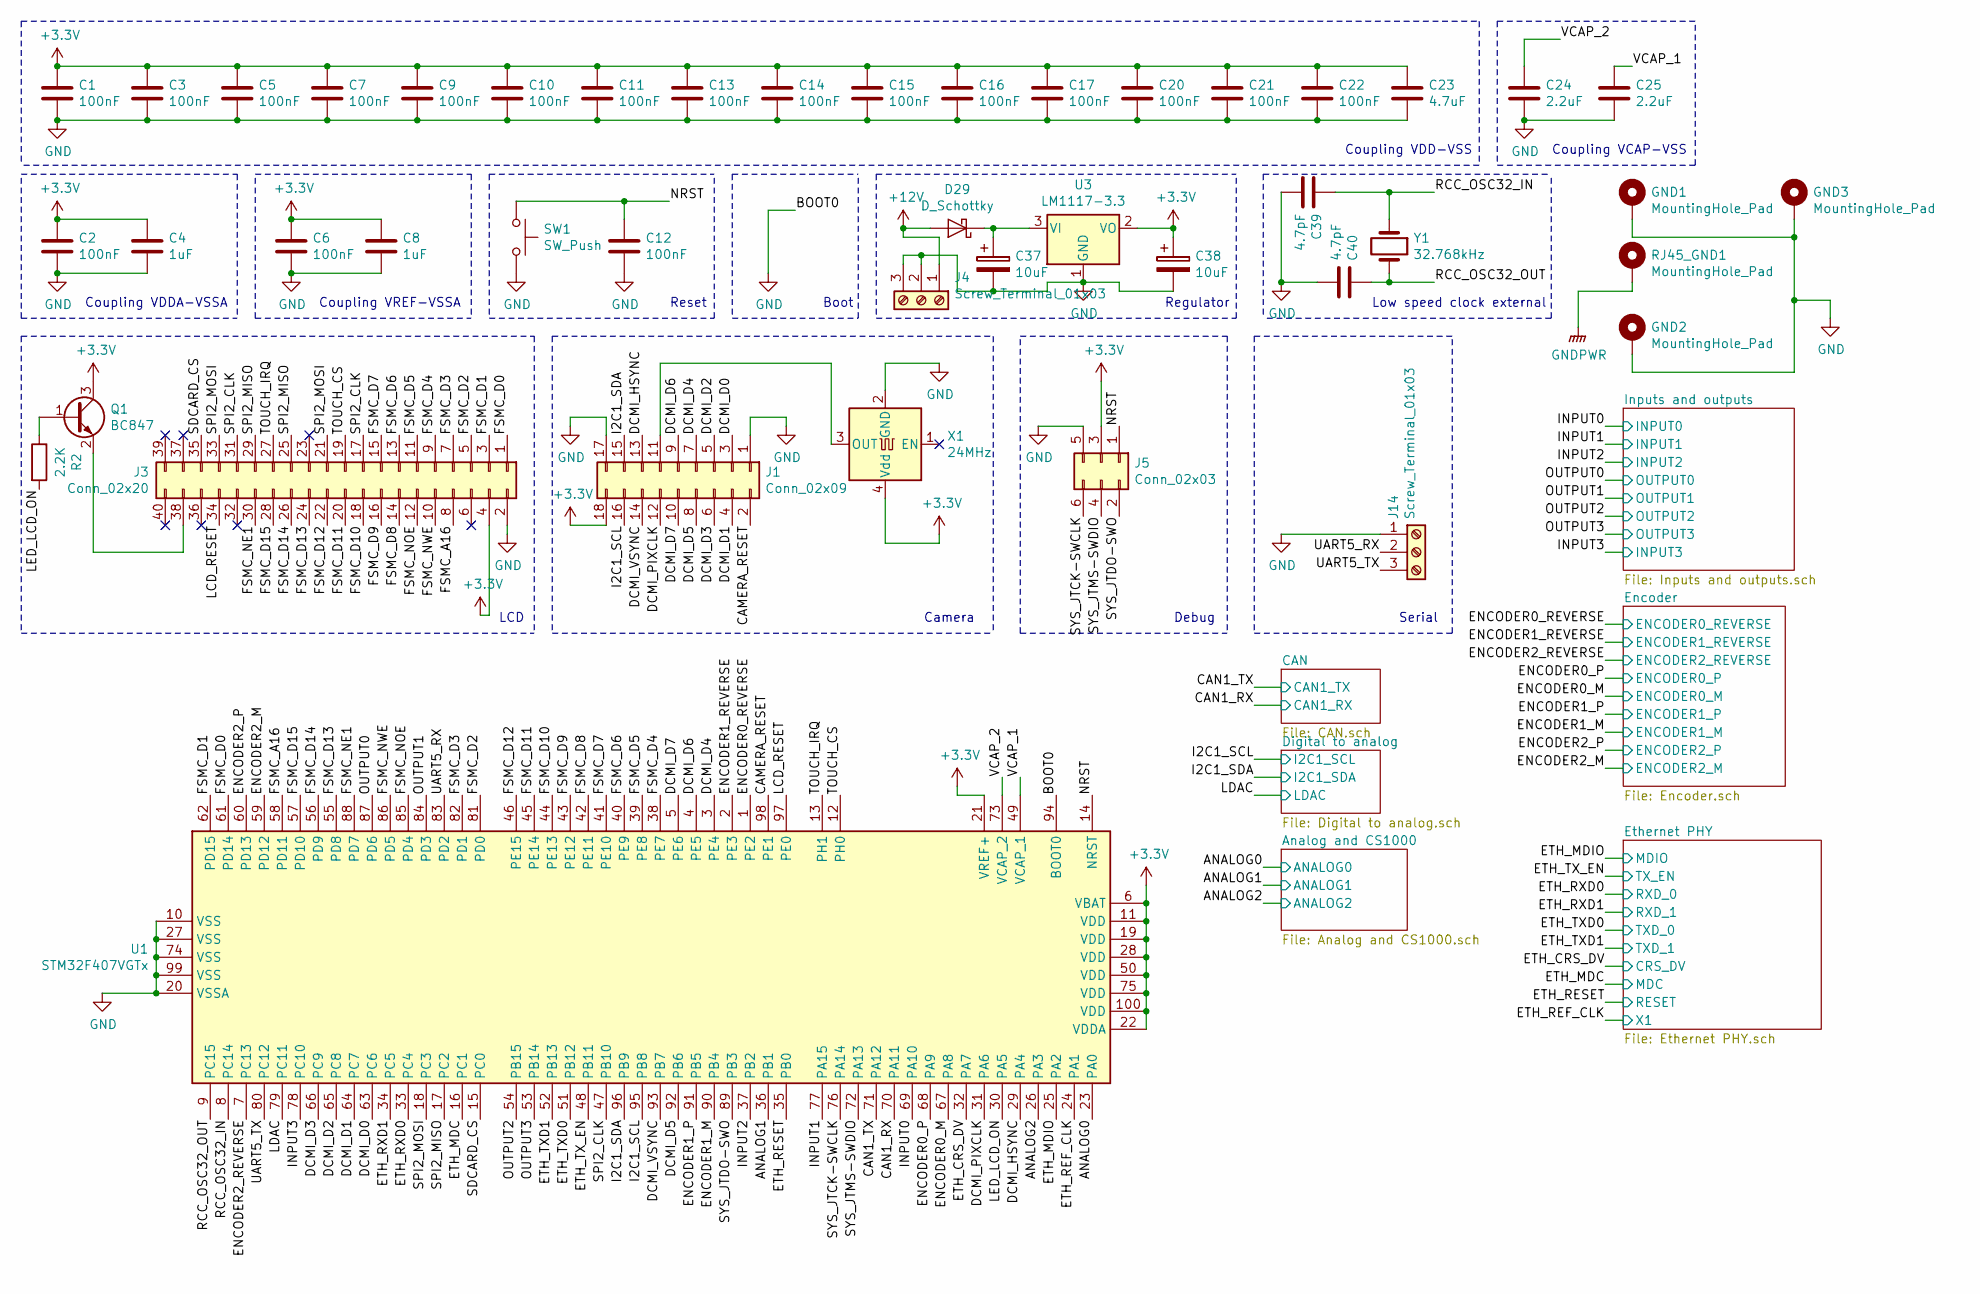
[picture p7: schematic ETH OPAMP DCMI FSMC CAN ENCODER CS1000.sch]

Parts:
C1, C2, C3, C5, C6, C7, C9, C10, C11, C12, C13, C14, C15, C16, C17, C20, C21, C22: 100nF; C_0603_1608Metric
C4, C8: 1uF; C_0603_1608Metric
C23: 4.7uF; C_0603_1608Metric
C24, C25: 2.2uF; C_0603_1608Metric
C37, C38: 10uF; CP_EIA-1608-08_AVX-J_Pad1.25x1.05mm_HandSolder
C39, C40: 4.7pF; C_0603_1608Metric
D29: D_Schottky; D_SOD-123
GND1, GND2, GND3: MountingHole_Pad; MountingHole_2.7mm_M2.5_DIN965_Pad
J1: Conn_02x09; PinHeader_2x09_P2.54mm_Vertical
J3: Conn_02x20; PinHeader_2x20_P2.54mm_Vertical
J4, J14: Screw_Terminal_01x03; TerminalBlock_Phoenix_MKDS-1,5-3_1x03_P5.00mm_Horizontal
J5: Conn_02x03; PinHeader_2x03_P2.54mm_Vertical
Q1: BC847; SOT-23
R2: 2.2K; R_0603_1608Metric
RJ45_GND1: MountingHole_Pad; MountingHole_2.7mm_M2.5_DIN965_Pad
SW1: SW_Push; SW_SPST_FSMSM
U1: STM32F407VGTx; LQFP-100_14x14mm_P0.5mm
U3: LM1117-3.3; SOT-223
X1: 24MHz; Crystal_SMD_EuroQuartz_MT-4Pin_3.2x2.5mm_HandSoldering
Y1: 32.768kHz; Crystal_SMD_MicroCrystal_CC7V-T1A-2Pin_3.2x1.5mm_HandSolder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

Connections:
+3V3: C1.1, C2.1, C3.1, C4.1, C5.1, C6.1, C7.1, C8.1, C9.1, C10.1, C11.1, C13.1, C14.1, C15.1, C16.1, C17.1, C20.1, C21.1, C22.1, C23.1, C38.1, J1.18, J3.4, J5.3, Q1.3 (C), U1.6 (VBAT), U1.11 (VDD), U1.19 (VDD), U1.21 (VREF+), U1.22 (VDDA), U1.28 (VDD), U1.50 (VDD), U1.75 (VDD), U1.100 (VDD), U3.2 (VO), X1.4 (Vdd); also elsewhere on the board
+12V: D29.2 (A), J4.1
/ANALOG0: U1.23 (PA0); also elsewhere on the board
/ANALOG1: U1.36 (PB1); also elsewhere on the board
/ANALOG2: U1.26 (PA3); also elsewhere on the board
/CAMERA_RESET: J1.2, U1.98 (PE1)
/CAN1_RX: U1.70 (PA11); also elsewhere on the board
/CAN1_TX: U1.71 (PA12); also elsewhere on the board
/DCMI_D0: J1.3, U1.63 (PC6)
/DCMI_D1: J1.4, U1.64 (PC7)
/DCMI_D2: J1.5, U1.65 (PC8)
/DCMI_D3: J1.6, U1.66 (PC9)
/DCMI_D4: J1.7, U1.3 (PE4)
/DCMI_D5: J1.8, U1.92 (PB6)
/DCMI_D6: J1.9, U1.4 (PE5)
/DCMI_D7: J1.10, U1.5 (PE6)
/DCMI_HSYNC: J1.13, U1.29 (PA4)
/DCMI_PIXCLK: J1.12, U1.31 (PA6)
/DCMI_VSYNC: J1.14, U1.93 (PB7)
/ENCODER0_M: U1.67 (PA8); also elsewhere on the board
/ENCODER0_P: U1.68 (PA9); also elsewhere on the board
/ENCODER0_REVERSE: U1.1 (PE2); also elsewhere on the board
/ENCODER1_M: U1.90 (PB4); also elsewhere on the board
/ENCODER1_P: U1.91 (PB5); also elsewhere on the board
/ENCODER1_REVERSE: U1.2 (PE3); also elsewhere on the board
/ENCODER2_M: U1.59 (PD12); also elsewhere on the board
/ENCODER2_P: U1.60 (PD13); also elsewhere on the board
/ENCODER2_REVERSE: U1.7 (PC13); also elsewhere on the board
/ETH_CRS_DV: U1.32 (PA7); also elsewhere on the board
/ETH_MDC: U1.16 (PC1); also elsewhere on the board
/ETH_MDIO: U1.25 (PA2); also elsewhere on the board
/ETH_REF_CLK: U1.24 (PA1); also elsewhere on the board
/ETH_RESET: U1.35 (PB0); also elsewhere on the board
/ETH_RXD0: U1.33 (PC4); also elsewhere on the board
/ETH_RXD1: U1.34 (PC5); also elsewhere on the board
/ETH_TXD0: U1.51 (PB12); also elsewhere on the board
/ETH_TXD1: U1.52 (PB13); also elsewhere on the board
/ETH_TX_EN: U1.48 (PB11); also elsewhere on the board
/FSMC_A16: J3.8, U1.58 (PD11)
/FSMC_D0: J3.1, U1.61 (PD14)
/FSMC_D1: J3.3, U1.62 (PD15)
/FSMC_D2: J3.5, U1.81 (PD0)
/FSMC_D3: J3.7, U1.82 (PD1)
/FSMC_D4: J3.9, U1.38 (PE7)
/FSMC_D5: J3.11, U1.39 (PE8)
/FSMC_D6: J3.13, U1.40 (PE9)
/FSMC_D7: J3.15, U1.41 (PE10)
/FSMC_D8: J3.14, U1.42 (PE11)
/FSMC_D9: J3.16, U1.43 (PE12)
/FSMC_D10: J3.18, U1.44 (PE13)
/FSMC_D11: J3.20, U1.45 (PE14)
/FSMC_D12: J3.22, U1.46 (PE15)
/FSMC_D13: J3.24, U1.55 (PD8)
/FSMC_D14: J3.26, U1.56 (PD9)
/FSMC_D15: J3.28, U1.57 (PD10)
/FSMC_NE1: J3.30, U1.88 (PD7)
/FSMC_NOE: J3.12, U1.85 (PD4)
/FSMC_NWE: J3.10, U1.86 (PD5)
/I2C1_SCL: J1.16, U1.95 (PB8); also elsewhere on the board
/I2C1_SDA: J1.15, U1.96 (PB9); also elsewhere on the board
/INPUT0: U1.69 (PA10); also elsewhere on the board
/INPUT1: U1.77 (PA15); also elsewhere on the board
/INPUT2: U1.37 (PB2); also elsewhere on the board
/INPUT3: U1.78 (PC10); also elsewhere on the board
/LCD_RESET: J3.34, U1.97 (PE0)
/LDAC: U1.79 (PC11); also elsewhere on the board
/LED_LCD_ON: R2.2, U1.30 (PA5)
/NRST: C12.1, J5.1, SW1.1, U1.14 (NRST)
/OUTPUT0: U1.87 (PD6); also elsewhere on the board
/OUTPUT1: U1.84 (PD3); also elsewhere on the board
/OUTPUT2: U1.54 (PB15); also elsewhere on the board
/OUTPUT3: U1.53 (PB14); also elsewhere on the board
/RCC_OSC32_IN: C39.1, U1.8 (PC14), Y1.1
/RCC_OSC32_OUT: C40.1, U1.9 (PC15), Y1.2
/SDCARD_CS: J3.35, U1.15 (PC0)
/SPI2_CLK: J3.17, J3.31, U1.47 (PB10)
/SPI2_MISO: J3.25, J3.29, U1.17 (PC2)
/SPI2_MOSI: J3.21, J3.33, U1.18 (PC3)
/SYS_JTCK-SWCLK: J5.6, U1.76 (PA14)
/SYS_JTDO-SWO: J5.2, U1.89 (PB3)
/SYS_JTMS-SWDIO: J5.4, U1.72 (PA13)
/TOUCH_CS: J3.19, U1.12 (PH0)
/TOUCH_IRQ: J3.27, U1.13 (PH1)
/UART5_RX: J14.2, U1.83 (PD2)
/UART5_TX: J14.3, U1.80 (PC12)
/VCAP_1: C25.1, U1.49 (VCAP_1)
/VCAP_2: C24.1, U1.73 (VCAP_2)
GND: C1.2, C2.2, C3.2, C4.2, C5.2, C6.2, C7.2, C8.2, C9.2, C10.2, C11.2, C12.2, C13.2, C14.2, C15.2, C16.2, C17.2, C20.2, C21.2, C22.2, C23.2, C24.2, C25.2, C37.2, C38.2, C39.2, C40.2, GND1.1, GND2.1, GND3.1, J1.1, J1.17, J3.2, J4.2, J4.3, J5.5, J14.1, SW1.2, U1.10 (VSS), U1.20 (VSSA), U1.27 (VSS), U1.74 (VSS), U1.94 (BOOT0), U1.99 (VSS), U3.1 (GND), X1.2 (GND); also elsewhere on the board
GNDPWR: RJ45_GND1.1; also elsewhere on the board
unnamed: C37.1, D29.1 (K), U3.3 (VI)
unnamed: J1.11, X1.3 (OUT)
unnamed: J3.38, Q1.2 (E)
unnamed: Q1.1 (B), R2.1

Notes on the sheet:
Coupling VDD-VSS
Coupling VCAP-VSS
Coupling VDDA-VSSA
Coupling VREF-VSSA
Reset
Boot
Regulator
LCD
Camera
Low speed clock external
Debug
Serial

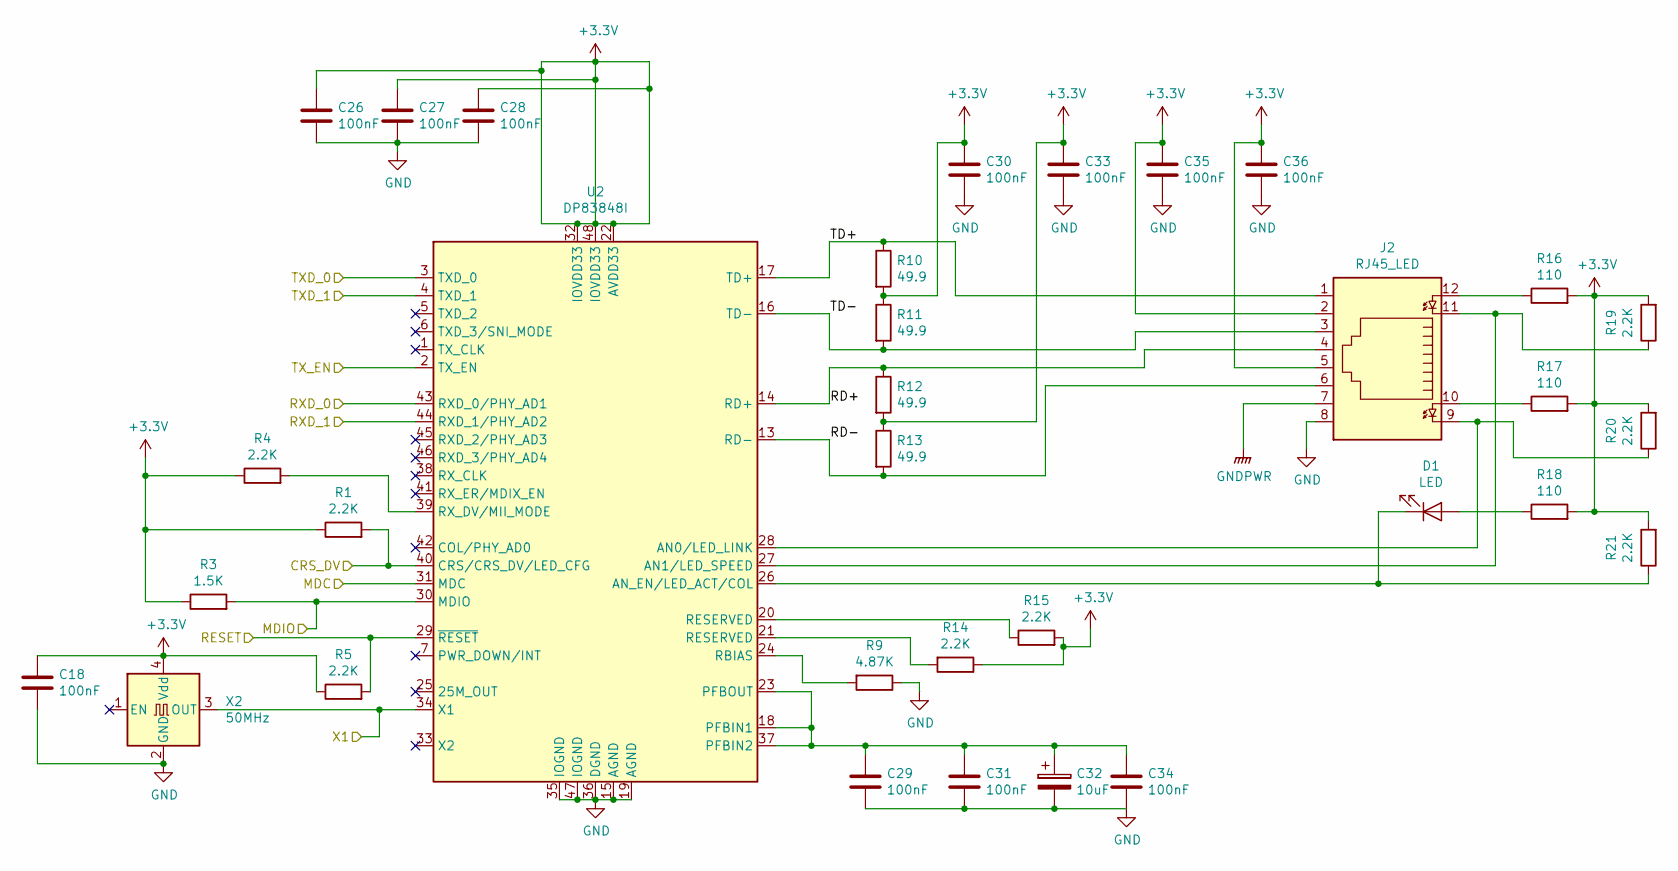
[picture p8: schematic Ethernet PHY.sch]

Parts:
C18, C26, C27, C28, C29, C30, C31, C33, C34, C35, C36: 100nF; C_0603_1608Metric
C32: 10uF; CP_EIA-1608-08_AVX-J_Pad1.25x1.05mm_HandSolder
D1: LED; LED_0603_1608Metric
J2: RJ45_LED; RJ45_Wuerth_7499010121A_Horizontal
R1, R4, R5, R14, R15, R19, R20, R21: 2.2K; R_0603_1608Metric
R3: 1.5K; R_0603_1608Metric
R9: 4.87K; R_0603_1608Metric
R10, R11, R12, R13: 49.9; R_0603_1608Metric
R16, R17, R18: 110; R_0603_1608Metric
U2: DP83848I; LQFP-48_7x7mm_P0.5mm
X2: 50MHz; Crystal_SMD_EuroQuartz_MT-4Pin_3.2x2.5mm_HandSoldering

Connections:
+3V3: C18.1, C26.1, C27.1, C28.1, C30.1, C33.1, C35.1, C36.1, J2.2, J2.5, R1.1, R3.1, R4.1, R5.1, R10.2, R11.1, R12.2, R13.1, R14.1, R15.2, R16.2, R17.2, R18.2, R19.2, R20.2, R21.2, U2.22 (AVDD33), U2.32 (IOVDD33), U2.48 (IOVDD33), X2.4 (Vdd); also elsewhere on the board
/ETH_CRS_DV: R1.2, U2.40 (CRS/CRS_DV/LED_CFG); also elsewhere on the board
/ETH_MDC: U2.31 (MDC); also elsewhere on the board
/ETH_MDIO: R3.2, U2.30 (MDIO); also elsewhere on the board
/ETH_REF_CLK: U2.34 (X1), X2.3 (OUT); also elsewhere on the board
/ETH_RESET: R5.2, U2.29 (~RESET~); also elsewhere on the board
/ETH_RXD0: U2.43 (RXD_0/PHY_AD1); also elsewhere on the board
/ETH_RXD1: U2.44 (RXD_1/PHY_AD2); also elsewhere on the board
/ETH_TXD0: U2.3 (TXD_0); also elsewhere on the board
/ETH_TXD1: U2.4 (TXD_1); also elsewhere on the board
/ETH_TX_EN: U2.2 (TX_EN); also elsewhere on the board
/Ethernet PHY/RD+: J2.4, R12.1, U2.14 (RD+)
/Ethernet PHY/RD-: J2.6, R13.2, U2.13 (RD-)
/Ethernet PHY/TD+: J2.1, R10.1, U2.17 (TD+)
/Ethernet PHY/TD-: J2.3, R11.2, U2.16 (TD-)
GND: C18.2, C26.2, C27.2, C28.2, C29.2, C30.2, C31.2, C32.2, C33.2, C34.2, C35.2, C36.2, J2.8, R9.1, U2.15 (AGND), U2.19 (AGND), U2.35 (IOGND), U2.36 (DGND), U2.47 (IOGND), X2.2 (GND); also elsewhere on the board
GNDPWR: J2.7; also elsewhere on the board
unnamed: C29.1, C31.1, C32.1, C34.1, U2.18 (PFBIN1), U2.23 (PFBOUT), U2.37 (PFBIN2)
unnamed: D1.1 (K), R21.1, U2.26 (AN_EN/LED_ACT/COL)
unnamed: D1.2 (A), R18.1
unnamed: J2.9, R20.1, U2.28 (AN0/LED_LINK)
unnamed: J2.10, R17.1
unnamed: J2.11, R19.1, U2.27 (AN1/LED_SPEED)
unnamed: J2.12, R16.1
unnamed: R4.2, U2.39 (RX_DV/MII_MODE)
unnamed: R9.2, U2.24 (RBIAS)
unnamed: R14.2, U2.21 (RESERVED)
unnamed: R15.1, U2.20 (RESERVED)

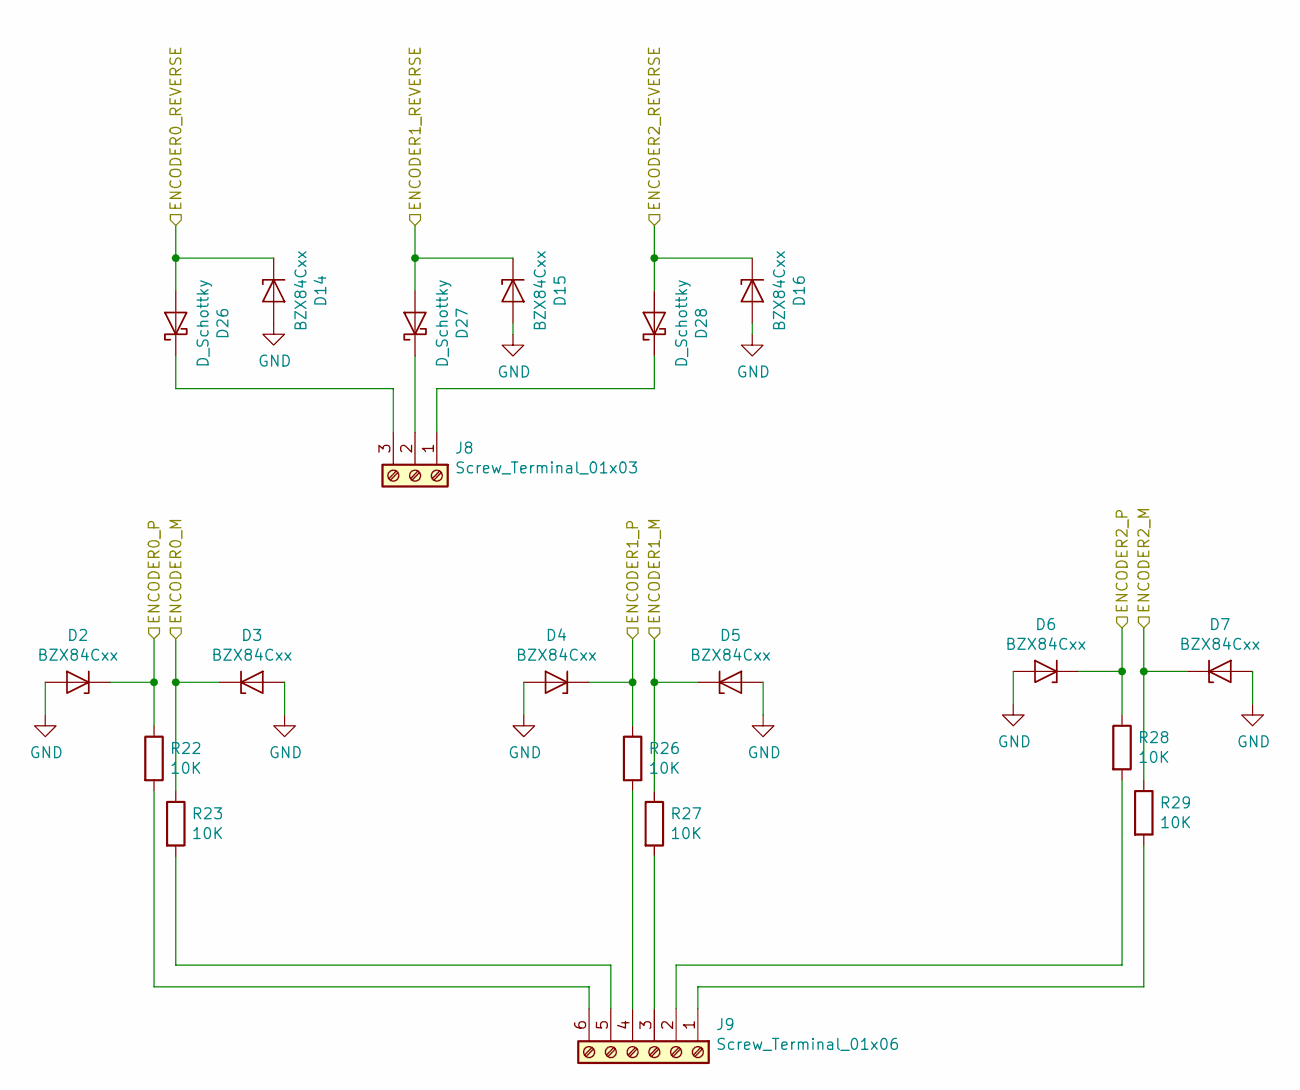
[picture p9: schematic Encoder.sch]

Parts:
D2, D3, D4, D5, D6, D7, D14, D15, D16: BZX84Cxx; D_SOT-23_ANK
D26, D27, D28: D_Schottky; D_SOD-123
J8: Screw_Terminal_01x03; TerminalBlock_Phoenix_MKDS-1,5-3_1x03_P5.00mm_Horizontal
J9: Screw_Terminal_01x06; TerminalBlock_Phoenix_MKDS-1,5-6_1x06_P5.00mm_Horizontal
R22, R23, R26, R27, R28, R29: 10K; R_0603_1608Metric

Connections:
/ENCODER0_M: D3.1 (K), R23.1; also elsewhere on the board
/ENCODER0_P: D2.1 (K), R22.1; also elsewhere on the board
/ENCODER0_REVERSE: D14.1 (K), D26.2 (A); also elsewhere on the board
/ENCODER1_M: D5.1 (K), R27.1; also elsewhere on the board
/ENCODER1_P: D4.1 (K), R26.1; also elsewhere on the board
/ENCODER1_REVERSE: D15.1 (K), D27.2 (A); also elsewhere on the board
/ENCODER2_M: D7.1 (K), R29.1; also elsewhere on the board
/ENCODER2_P: D6.1 (K), R28.1; also elsewhere on the board
/ENCODER2_REVERSE: D16.1 (K), D28.2 (A); also elsewhere on the board
GND: D2.2 (A), D3.2 (A), D4.2 (A), D5.2 (A), D6.2 (A), D7.2 (A), D14.2 (A), D15.2 (A), D16.2 (A); also elsewhere on the board
unnamed: D26.1 (K), J8.3
unnamed: D27.1 (K), J8.2
unnamed: D28.1 (K), J8.1
unnamed: J9.1, R29.2
unnamed: J9.2, R28.2
unnamed: J9.3, R27.2
unnamed: J9.4, R26.2
unnamed: J9.5, R23.2
unnamed: J9.6, R22.2

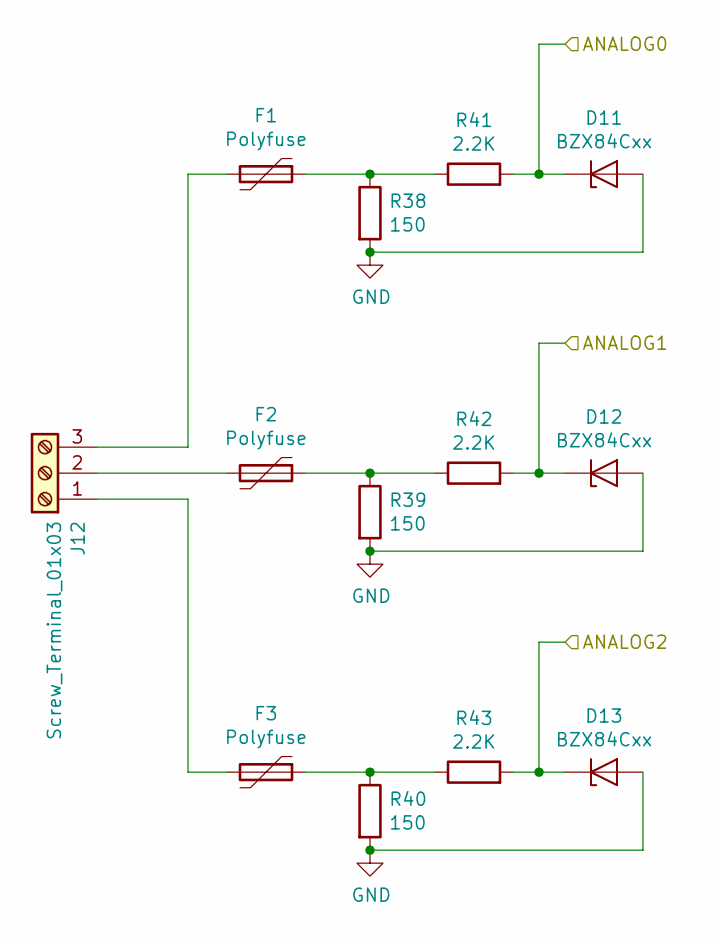
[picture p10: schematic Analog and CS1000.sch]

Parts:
D11, D12, D13: BZX84Cxx; D_SOT-23_ANK
F1, F2, F3: Polyfuse; R_0603_1608Metric
J12: Screw_Terminal_01x03; TerminalBlock_Phoenix_MKDS-1,5-3_1x03_P5.00mm_Horizontal
R38, R39, R40: 150; R_1206_3216Metric
R41, R42, R43: 2.2K; R_0603_1608Metric

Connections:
/ANALOG0: D11.1 (K), R41.2; also elsewhere on the board
/ANALOG1: D12.1 (K), R42.2; also elsewhere on the board
/ANALOG2: D13.1 (K), R43.2; also elsewhere on the board
GND: D11.2 (A), D12.2 (A), D13.2 (A), R38.2, R39.2, R40.2; also elsewhere on the board
unnamed: F1.1, R38.1, R41.1
unnamed: F1.2, J12.3
unnamed: F2.1, R39.1, R42.1
unnamed: F2.2, J12.2
unnamed: F3.1, R40.1, R43.1
unnamed: F3.2, J12.1

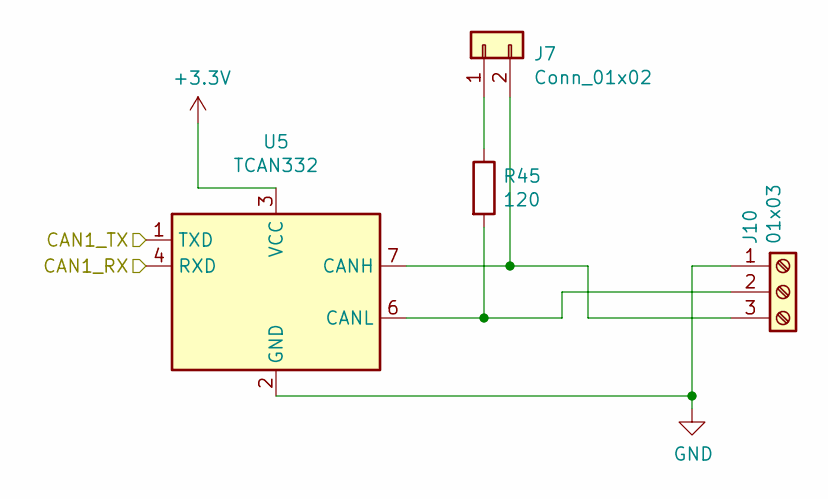
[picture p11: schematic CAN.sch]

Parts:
J7: Conn_01x02; PinHeader_1x02_P2.54mm_Vertical
J10: 01x03; TerminalBlock_Phoenix_MKDS-1,5-3_1x03_P5.00mm_Horizontal
R45: 120; R_0603_1608Metric
U5: TCAN332; SOIC-8_3.9x4.9mm_P1.27mm

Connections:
+3V3: U5.3 (VCC); also elsewhere on the board
/CAN1_RX: U5.4 (RXD); also elsewhere on the board
/CAN1_TX: U5.1 (TXD); also elsewhere on the board
GND: J10.1, U5.2 (GND); also elsewhere on the board
unnamed: J7.1, R45.1
unnamed: J10.2, R45.2, U5.6 (CANL)
unnamed: J7.2, J10.3, U5.7 (CANH)

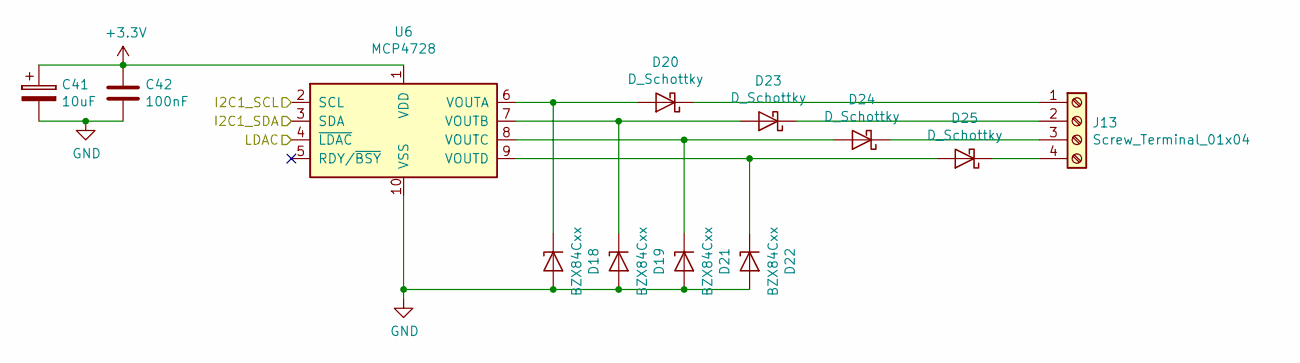
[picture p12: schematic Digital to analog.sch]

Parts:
C41: 10uF; CP_EIA-1608-08_AVX-J_Pad1.25x1.05mm_HandSolder
C42: 100nF; C_0603_1608Metric
D18, D19, D21, D22: BZX84Cxx; D_SOT-23_ANK
D20, D23, D24, D25: D_Schottky; D_SOD-123
J13: Screw_Terminal_01x04; TerminalBlock_Phoenix_MKDS-1,5-4_1x04_P5.00mm_Horizontal
U6: MCP4728; MSOP-10_3x3mm_P0.5mm

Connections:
+3V3: C41.1, C42.1, U6.1 (VDD); also elsewhere on the board
/I2C1_SCL: U6.2 (SCL); also elsewhere on the board
/I2C1_SDA: U6.3 (SDA); also elsewhere on the board
/LDAC: U6.4 (~LDAC); also elsewhere on the board
GND: C41.2, C42.2, D18.2 (A), D19.2 (A), D21.2 (A), D22.2 (A), U6.10 (VSS); also elsewhere on the board
unnamed: D18.1 (K), D20.2 (A), U6.6 (VOUTA)
unnamed: D19.1 (K), D23.2 (A), U6.7 (VOUTB)
unnamed: D20.1 (K), J13.1
unnamed: D21.1 (K), D24.2 (A), U6.8 (VOUTC)
unnamed: D22.1 (K), D25.2 (A), U6.9 (VOUTD)
unnamed: D23.1 (K), J13.2
unnamed: D24.1 (K), J13.3
unnamed: D25.1 (K), J13.4

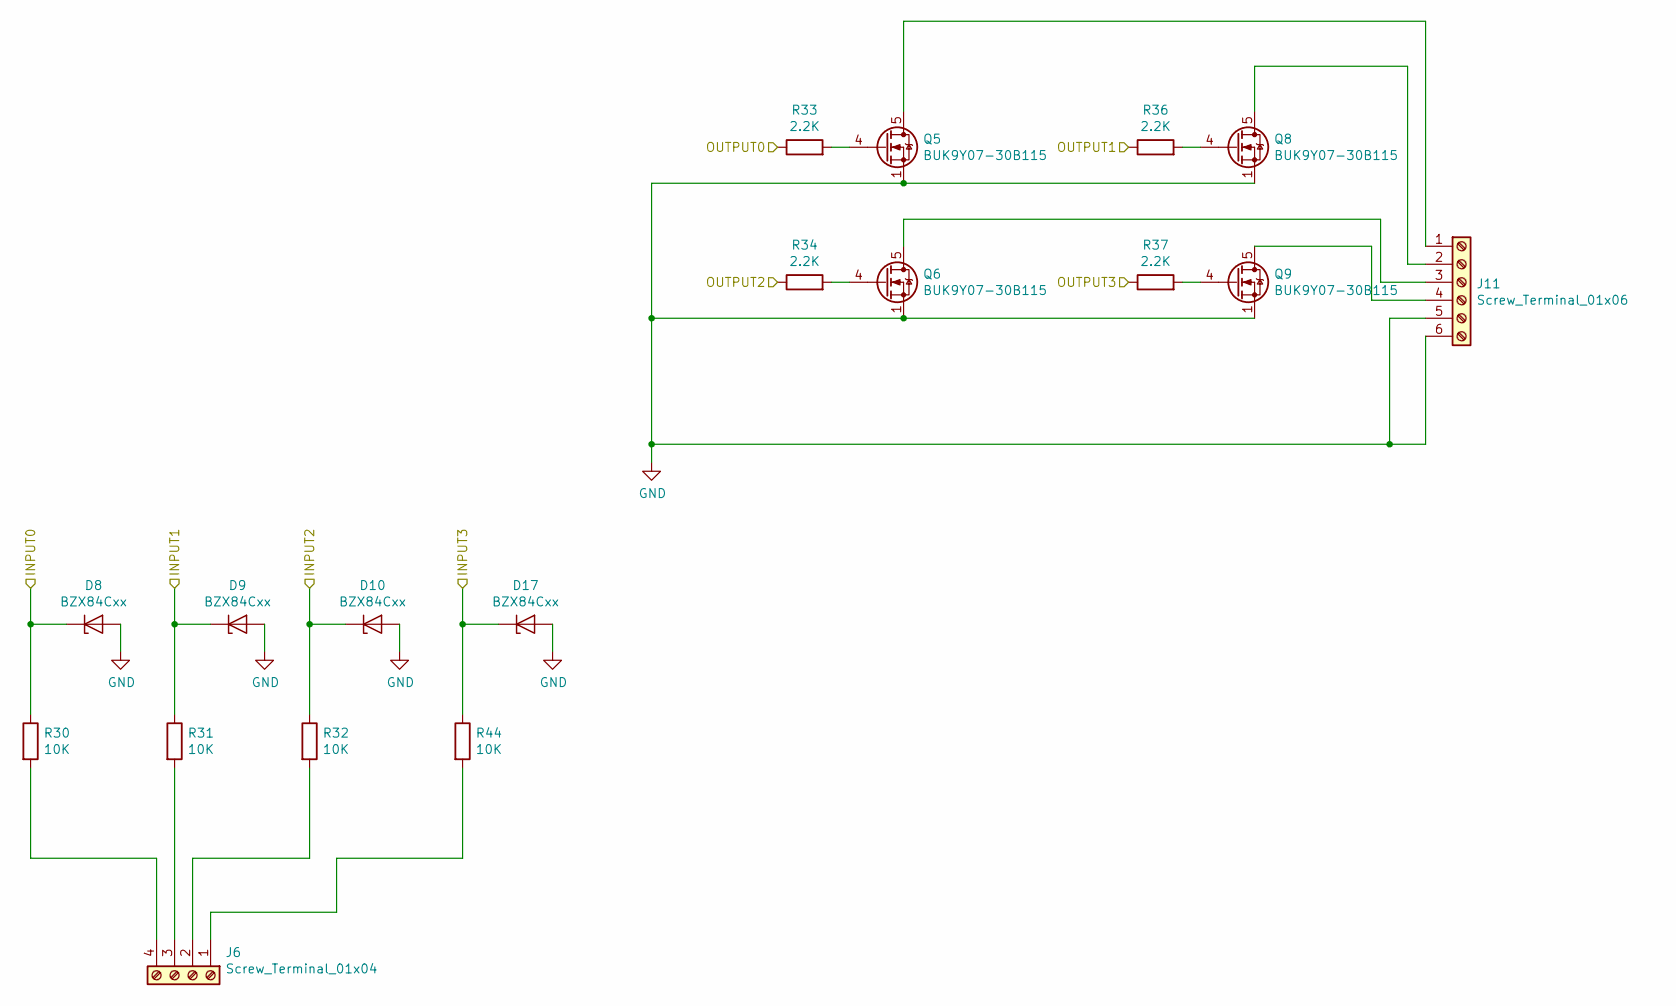
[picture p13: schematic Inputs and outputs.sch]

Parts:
D8, D9, D10, D17: BZX84Cxx; D_SOT-23_ANK
J6: Screw_Terminal_01x04; TerminalBlock_Phoenix_MKDS-1,5-4_1x04_P5.00mm_Horizontal
J11: Screw_Terminal_01x06; TerminalBlock_Phoenix_MKDS-1,5-6_1x06_P5.00mm_Horizontal
Q5, Q6, Q8, Q9: BUK9Y07-30B115; LFPAK56
R30, R31, R32, R44: 10K; R_0603_1608Metric
R33, R34, R36, R37: 2.2K; R_0603_1608Metric

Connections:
/INPUT0: D8.1 (K), R30.1; also elsewhere on the board
/INPUT1: D9.1 (K), R31.1; also elsewhere on the board
/INPUT2: D10.1 (K), R32.1; also elsewhere on the board
/INPUT3: D17.1 (K), R44.1; also elsewhere on the board
/OUTPUT0: R33.1; also elsewhere on the board
/OUTPUT1: R36.1; also elsewhere on the board
/OUTPUT2: R34.1; also elsewhere on the board
/OUTPUT3: R37.1; also elsewhere on the board
GND: D8.2 (A), D9.2 (A), D10.2 (A), D17.2 (A), J11.5, J11.6, Q5.1 (S), Q5.2 (S), Q5.3 (S), Q6.1 (S), Q6.2 (S), Q6.3 (S), Q8.1 (S), Q8.2 (S), Q8.3 (S), Q9.1 (S), Q9.2 (S), Q9.3 (S); also elsewhere on the board
unnamed: J6.1, R44.2
unnamed: J6.2, R32.2
unnamed: J6.3, R31.2
unnamed: J6.4, R30.2
unnamed: J11.1, Q5.5 (D)
unnamed: J11.2, Q8.5 (D)
unnamed: J11.3, Q6.5 (D)
unnamed: J11.4, Q9.5 (D)
unnamed: Q5.4 (G), R33.2
unnamed: Q6.4 (G), R34.2
unnamed: Q8.4 (G), R36.2
unnamed: Q9.4 (G), R37.2

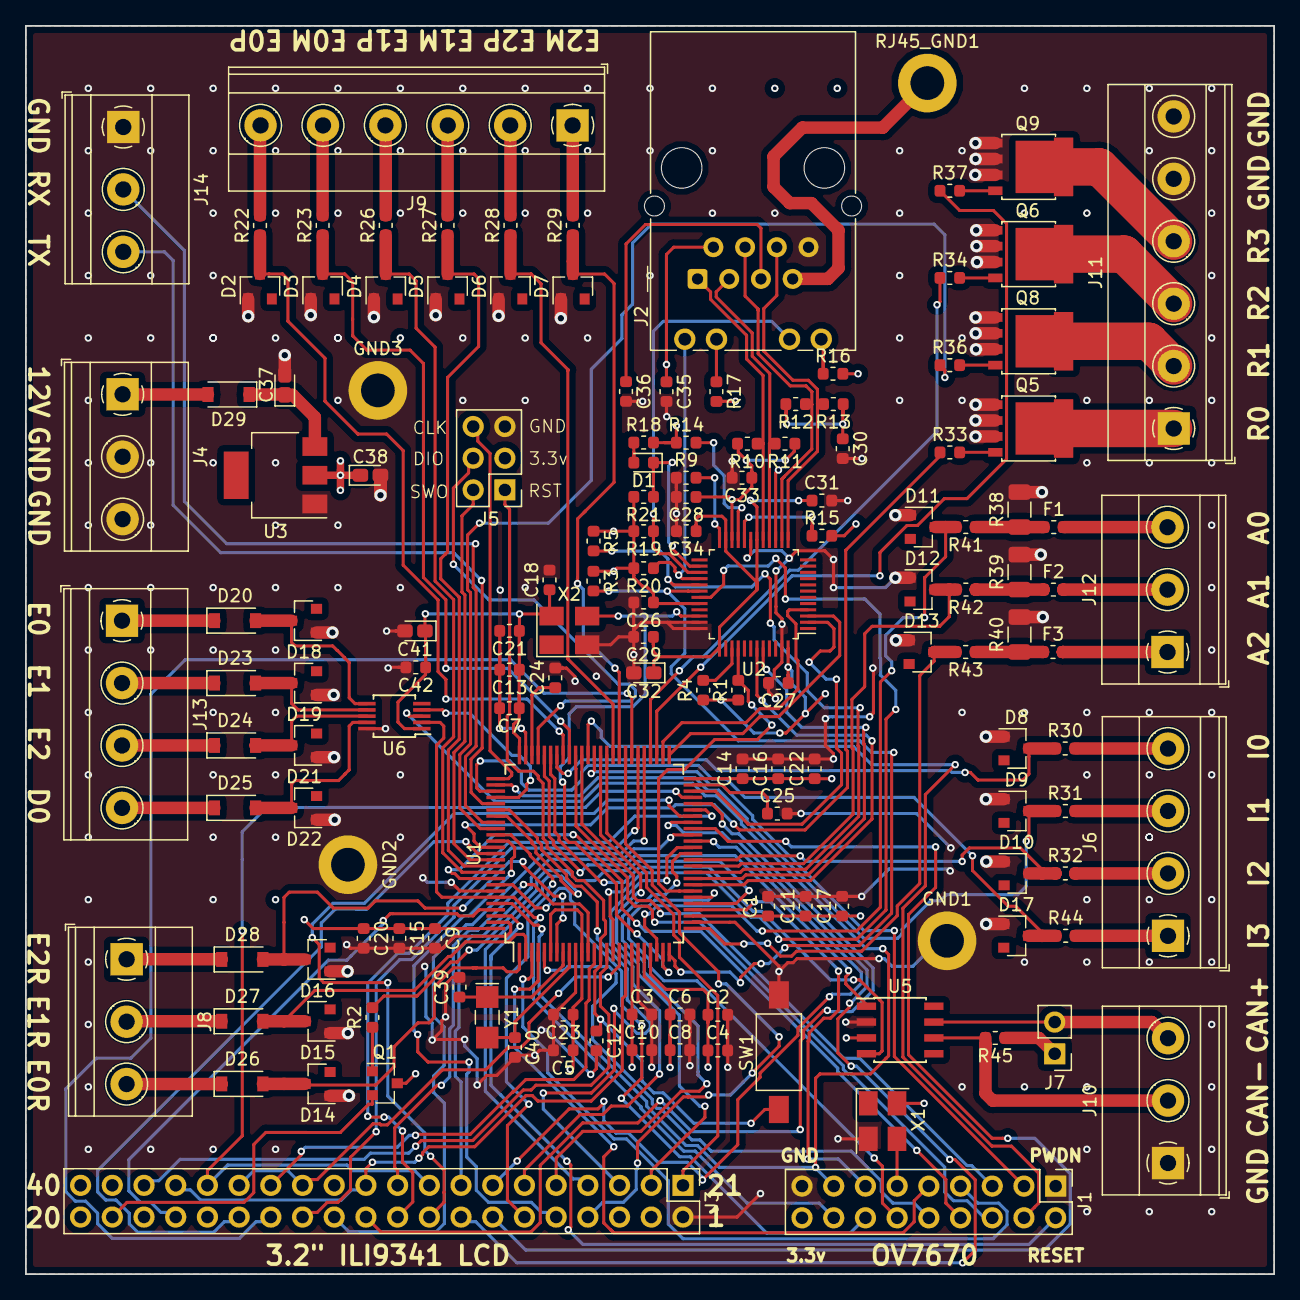
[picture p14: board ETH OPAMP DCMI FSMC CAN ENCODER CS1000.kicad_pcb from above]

Board: 4 copper layers, 100.0 x 100.0 mm, 144 parts (0 on the bottom side), 146 nets.

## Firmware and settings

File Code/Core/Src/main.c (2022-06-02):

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
/* Includes ------------------------------------------------------------------*/
#include "main.h"
#include "lwip.h"

/* USER CODE BEGIN Includes */
#include "STM32_ILI9341_FSMC_16_Bit/ili9341.h"
#include "MCP4728/mcp4728.h"
/* USER CODE END Includes */

/* USER CODE BEGIN PD */
#define min(a,b) (((a)<(b))?(a):(b))
/* USER CODE END PD */

 ADC_HandleTypeDef hadc1;

CAN_HandleTypeDef hcan1;

DCMI_HandleTypeDef hdcmi;

I2C_HandleTypeDef hi2c1;

RTC_HandleTypeDef hrtc;

SPI_HandleTypeDef hspi2;

TIM_HandleTypeDef htim1;
TIM_HandleTypeDef htim3;
TIM_HandleTypeDef htim4;

UART_HandleTypeDef huart5;

SRAM_HandleTypeDef hsram1;

void SystemClock_Config(void);
static void MX_GPIO_Init(void);
static void MX_FSMC_Init(void);
static void MX_DCMI_Init(void);
static void MX_SPI2_Init(void);
static void MX_TIM1_Init(void);
static void MX_TIM3_Init(void);
static void MX_ADC1_Init(void);
static void MX_CAN1_Init(void);
static void MX_RTC_Init(void);
static void MX_TIM4_Init(void);
static void MX_UART5_Init(void);
static void MX_I2C1_Init(void);
/* USER CODE BEGIN PFP */
void demoLCD(int i);
unsigned long testFillScreen();
unsigned long testText();
unsigned long testLines(uint16_t color);
unsigned long testFastLines(uint16_t color1, uint16_t color2);
unsigned long testRects(uint16_t color);
unsigned long testFilledRects(uint16_t color1, uint16_t color2);
unsigned long testFilledCircles(uint8_t radius, uint16_t color);
unsigned long testCircles(uint8_t radius, uint16_t color);
unsigned long testTriangles();
unsigned long testFilledTriangles();
unsigned long testRoundRects();
unsigned long testFilledRoundRects();
unsigned long testDrawImage();
/* USER CODE END PFP */

/**
  * @brief  The application entry point.
  * @retval int
  */
int main(void)
{
  /* MCU Configuration--------------------------------------------------------*/

  /* Reset of all peripherals, Initializes the Flash interface and the Systick. */
  HAL_Init();

  /* Configure the system clock */
  SystemClock_Config();

  /* Initialize all configured peripherals */
  MX_GPIO_Init();
  MX_FSMC_Init();
  MX_DCMI_Init();
  MX_SPI2_Init();
  MX_TIM1_Init();
  MX_TIM3_Init();
  MX_ADC1_Init();
  MX_CAN1_Init();
  MX_RTC_Init();
  MX_TIM4_Init();
  MX_UART5_Init();
  MX_LWIP_Init();
  MX_I2C1_Init();
  /* USER CODE BEGIN 2 */

  /* Start up LCD */
  HAL_GPIO_WritePin(LCD_RESET_GPIO_Port, LCD_RESET_Pin, GPIO_PIN_SET);
  LCD_BL_ON();
  lcdInit(&hspi2);
  //touchCalibrate();
  //lcdFillRGB(COLOR_BLACK);

  /* Write to MCP4728 */
  mcp4728_init(&hi2c1, 0x4); // Manufacturer I2C settings: A4 (A2 = 1, A1 = 0, A0 = 0)

  /* Set values */
  mcp4728_set_channel_value(MCP4728_CHANNEL_A, 4095);
  mcp4728_set_channel_value(MCP4728_CHANNEL_B, 3000);
  mcp4728_set_channel_value(MCP4728_CHANNEL_C, 2000);
  mcp4728_set_channel_value(MCP4728_CHANNEL_D, 1000);

  /* Set gain */
  mcp4728_set_channel_gain(MCP4728_CHANNEL_A, MCP4728_GAIN_1);
  mcp4728_set_channel_gain(MCP4728_CHANNEL_B, MCP4728_GAIN_1);
  mcp4728_set_channel_gain(MCP4728_CHANNEL_C, MCP4728_GAIN_1);
  mcp4728_set_channel_gain(MCP4728_CHANNEL_D, MCP4728_GAIN_1);

  /* Set power down */
  mcp4728_set_channel_power_down(MCP4728_CHANNEL_A, MCP4728_POWER_DOWN_NORMAL);
  mcp4728_set_channel_power_down(MCP4728_CHANNEL_B, MCP4728_POWER_DOWN_NORMAL);
  mcp4728_set_channel_power_down(MCP4728_CHANNEL_C, MCP4728_POWER_DOWN_NORMAL);
  mcp4728_set_channel_power_down(MCP4728_CHANNEL_D, MCP4728_POWER_DOWN_NORMAL);

  /* Set voltage reference */
  mcp4728_set_channel_vref(MCP4728_CHANNEL_A, MCP4728_VREF_VDD);
  mcp4728_set_channel_vref(MCP4728_CHANNEL_B, MCP4728_VREF_VDD);
  mcp4728_set_channel_vref(MCP4728_CHANNEL_C, MCP4728_VREF_VDD);
  mcp4728_set_channel_vref(MCP4728_CHANNEL_D, MCP4728_VREF_VDD);

  /* Multi write without EEPROM */
  mcp4728_multi_write_command();


  /* USER CODE END 2 */

  /* Infinite loop */
  /* USER CODE BEGIN WHILE */
  while (1)
  {
    /* USER CODE END WHILE */

    /* USER CODE BEGIN 3 */
	  //touchPrintCoordinates();
	  //HAL_Delay(500);

  }
  /* USER CODE END 3 */
}

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
/* USER CODE BEGIN 4 */
void demoLCD(int i)
{
	lcdSetOrientation(i % 4);

	uint32_t t = testFillScreen();
	lcdSetTextFont(&Font16);
	lcdSetCursor(0, lcdGetHeight() - lcdGetTextFont()->Height - 1);
	lcdSetTextColor(COLOR_WHITE, COLOR_BLACK);
	lcdPrintf("Time: %4lu ms", t);
	HAL_Delay(2000);

	t = HAL_GetTick();
	lcdTest();
	lcdSetTextFont(&Font16);
	lcdSetCursor(0, lcdGetHeight() - lcdGetTextFont()->Height - 1);
	lcdSetTextColor(COLOR_WHITE, COLOR_BLACK);
	lcdPrintf("Time: %4lu ms", HAL_GetTick() - t);
	HAL_Delay(2000);

	t = testText();
	lcdSetTextFont(&Font16);
	lcdSetCursor(0, lcdGetHeight() - lcdGetTextFont()->Height - 1);
	lcdSetTextColor(COLOR_WHITE, COLOR_BLACK);
	lcdPrintf("Time: %4lu ms", t);
	HAL_Delay(2000);

	lcdSetTextFont(&Font16);
	lcdSetCursor(0, lcdGetHeight() - lcdGetTextFont()->Height - 1);
	lcdSetTextColor(COLOR_WHITE, COLOR_BLACK);
	lcdPrintf("Time: %4lu ms", testLines(COLOR_CYAN));
	HAL_Delay(2000);

	lcdSetTextFont(&Font16);
	lcdSetCursor(0, lcdGetHeight() - lcdGetTextFont()->Height - 1);
	lcdSetTextColor(COLOR_WHITE, COLOR_BLACK);
	lcdPrintf("Time: %4lu ms", testFastLines(COLOR_RED, COLOR_BLUE));
	HAL_Delay(2000);

	lcdSetTextFont(&Font16);
	lcdSetCursor(0, lcdGetHeight() - lcdGetTextFont()->Height - 1);
	lcdSetTextColor(COLOR_WHITE, COLOR_BLACK);
	lcdPrintf("Time: %4lu ms", testRects(COLOR_GREEN));
	HAL_Delay(2000);

	lcdSetTextFont(&Font16);
	lcdSetCursor(0, lcdGetHeight() - lcdGetTextFont()->Height - 1);
	lcdSetTextColor(COLOR_WHITE, COLOR_BLACK);
	lcdPrintf("Time: %4lu ms", testFilledRects(COLOR_YELLOW, COLOR_MAGENTA));
	HAL_Delay(2000);

	lcdSetTextFont(&Font16);
	lcdSetCursor(0, lcdGetHeight() - lcdGetTextFont()->Height - 1);
	lcdSetTextColor(COLOR_WHITE, COLOR_BLACK);
	lcdPrintf("Time: %4lu ms", testFilledCircles(10, COLOR_MAGENTA));
	HAL_Delay(2000);

	lcdSetTextFont(&Font16);
	lcdSetCursor(0, lcdGetHeight() - lcdGetTextFont()->Height - 1);
	lcdSetTextColor(COLOR_WHITE, COLOR_BLACK);
	lcdPrintf("Time: %4lu ms", testCircles(10, COLOR_WHITE));
	HAL_Delay(2000);

	lcdSetTextFont(&Font16);
	lcdSetCursor(0, lcdGetHeight() - lcdGetTextFont()->Height - 1);
	lcdSetTextColor(COLOR_WHITE, COLOR_BLACK);
	lcdPrintf("Time: %4lu ms", testTriangles());
	HAL_Delay(2000);

	lcdSetTextFont(&Font16);
	lcdSetCursor(0, lcdGetHeight() - lcdGetTextFont()->Height - 1);
	lcdSetTextColor(COLOR_WHITE, COLOR_BLACK);
	lcdPrintf("Time: %4lu ms", testFilledTriangles());
	HAL_Delay(2000);

	lcdSetTextFont(&Font16);
	lcdSetCursor(0, lcdGetHeight() - lcdGetTextFont()->Height - 1);
	lcdSetTextColor(COLOR_WHITE, COLOR_BLACK);
	lcdPrintf("Time: %4lu ms", testRoundRects());
	HAL_Delay(2000);

	lcdSetTextFont(&Font16);
	lcdSetCursor(0, lcdGetHeight() - lcdGetTextFont()->Height - 1);
	lcdSetTextColor(COLOR_WHITE, COLOR_BLACK);
	lcdPrintf("Time: %4lu ms", testFilledRoundRects());
	HAL_Delay(2000);

	lcdSetTextFont(&Font16);
	lcdSetCursor(0, lcdGetHeight() - lcdGetTextFont()->Height - 1);
	lcdSetTextColor(COLOR_WHITE, COLOR_BLACK);
	lcdPrintf("Time: %4lu ms", testDrawImage());
	HAL_Delay(2000);
}

unsigned long testFillScreen()
{
	unsigned long start = HAL_GetTick(), t = 0;
	lcdFillRGB(COLOR_BLACK);
	t += HAL_GetTick() - start;
	lcdSetCursor(0, 0);
	lcdSetTextFont(&Font24);
	lcdSetTextColor(COLOR_WHITE, COLOR_BLACK);
	lcdPrintf("BLACK");
	HAL_Delay(1000);
	start = HAL_GetTick();
	lcdFillRGB(COLOR_RED);
	t += HAL_GetTick() - start;
	lcdSetCursor(0, 0);
	lcdSetTextFont(&Font24);
	lcdSetTextColor(COLOR_WHITE, COLOR_BLACK);
	lcdPrintf("RED");
	HAL_Delay(1000);
	start = HAL_GetTick();
	lcdFillRGB(COLOR_GREEN);
	t += HAL_GetTick() - start;
	lcdSetCursor(0, 0);
	lcdSetTextFont(&Font24);
	lcdSetTextColor(COLOR_WHITE, COLOR_BLACK);
	lcdPrintf("GREEN");
	HAL_Delay(1000);
	start = HAL_GetTick();
	lcdFillRGB(COLOR_BLUE);
	t += HAL_GetTick() - start;
	lcdSetCursor(0, 0);
	lcdSetTextFont(&Font24);
	lcdSetTextColor(COLOR_WHITE, COLOR_BLACK);
	lcdPrintf("BLUE");
	HAL_Delay(1000);
	start = HAL_GetTick();
	lcdFillRGB(COLOR_BLACK);
	return t += HAL_GetTick() - start;
}

unsigned long testText()
{
	lcdFillRGB(COLOR_BLACK);
	unsigned long start = HAL_GetTick();
	lcdSetCursor(0, 0);
	lcdSetTextColor(COLOR_WHITE, COLOR_BLACK);
	lcdSetTextFont(&Font8);
	lcdPrintf("Hello World!\r\n");
	lcdSetTextColor(COLOR_YELLOW, COLOR_BLACK);
	lcdSetTextFont(&Font12);
	lcdPrintf("%i\r\n", 1234567890);
	lcdSetTextColor(COLOR_RED, COLOR_BLACK);
	lcdSetTextFont(&Font16);
	lcdPrintf("%#X\r\n", 0xDEADBEEF);
	lcdPrintf("\r\n");
	lcdSetTextColor(COLOR_GREEN, COLOR_BLACK);
	lcdSetTextFont(&Font20);
	lcdPrintf("Groop\r\n");
	lcdSetTextFont(&Font12);
	lcdPrintf("I implore thee,\r\n");
	lcdSetTextFont(&Font12);
	lcdPrintf("my foonting turlingdromes.\r\n");
	lcdPrintf("And hooptiously drangle me\r\n");
	lcdPrintf("with crinkly bindlewurdles,\r\n");
	lcdPrintf("Or I will rend thee\r\n");
	lcdPrintf("in the gobberwarts\r\n");
	lcdPrintf("with my blurglecruncheon,\r\n");
	lcdPrintf("see if I don't!\r\n");
	return HAL_GetTick() - start;
}

unsigned long testLines(uint16_t color)
{
  unsigned long start, t;
  int           x1, y1, x2, y2,
                w = lcdGetWidth(),
                h = lcdGetHeight();

  lcdFillRGB(COLOR_BLACK);

  x1 = y1 = 0;
  y2    = h - 1;
  start = HAL_GetTick();
  for(x2 = 0; x2 < w; x2 += 6) lcdDrawLine(x1, y1, x2, y2, color);
  x2 = w - 1;
  for(y2 = 0; y2 < h; y2 += 6) lcdDrawLine(x1, y1, x2, y2, color);
  t = HAL_GetTick() - start; // fillScreen doesn't count against timing

  HAL_Delay(1000);
  lcdFillRGB(COLOR_BLACK);

  x1 = w - 1;
  y1 = 0;
  y2 = h - 1;

  start = HAL_GetTick();

  for(x2 = 0; x2 < w; x2 += 6) lcdDrawLine(x1, y1, x2, y2, color);
  x2 = 0;
  for(y2 = 0; y2 < h; y2 += 6) lcdDrawLine(x1, y1, x2, y2, color);
  t += HAL_GetTick() - start;

  HAL_Delay(1000);
  lcdFillRGB(COLOR_BLACK);

  x1 = 0;
  y1 = h - 1;
  y2 = 0;
  start = HAL_GetTick();

  for(x2 = 0; x2 < w; x2 += 6) lcdDrawLine(x1, y1, x2, y2, color);
  x2 = w - 1;
  for(y2 = 0; y2 < h; y2 += 6) lcdDrawLine(x1, y1, x2, y2, color);
  t += HAL_GetTick() - start;

  HAL_Delay(1000);
  lcdFillRGB(COLOR_BLACK);

  x1 = w - 1;
  y1 = h - 1;
  y2 = 0;

  start = HAL_GetTick();

  for(x2 = 0; x2 < w; x2 += 6) lcdDrawLine(x1, y1, x2, y2, color);
  x2 = 0;
  for(y2 = 0; y2 < h; y2 += 6) lcdDrawLine(x1, y1, x2, y2, color);

  return t += HAL_GetTick() - start;
}

unsigned long testFastLines(uint16_t color1, uint16_t color2)
{
  unsigned long start;
  int x, y, w = lcdGetWidth(), h = lcdGetHeight();

  lcdFillRGB(COLOR_BLACK);
  start = HAL_GetTick();
  for(y = 0; y < h; y += 5) lcdDrawHLine(0, w, y, color1);
  for(x = 0; x < w; x += 5) lcdDrawVLine(x, 0, h, color2);

  return HAL_GetTick() - start;
}

unsigned long testRects(uint16_t color)
{
  unsigned long start;
  int n, i, i2,
      cx = lcdGetWidth()  / 2,
      cy = lcdGetHeight() / 2;

  lcdFillRGB(COLOR_BLACK);
  n = min(lcdGetWidth(), lcdGetHeight());
  start = HAL_GetTick();
  for(i = 2; i < n; i += 6)
  {
    i2 = i / 2;
    lcdDrawRect(cx - i2, cy - i2, i, i, color);
  }

  return HAL_GetTick() - start;
}

unsigned long testFilledRects(uint16_t color1, uint16_t color2)
{
  unsigned long start, t = 0;
  int n, i, i2,
      cx = lcdGetWidth() / 2 - 1,
      cy = lcdGetHeight() / 2 - 1;

  lcdFillRGB(COLOR_BLACK);
  n = min(lcdGetWidth(), lcdGetHeight());

  for(i = n; i > 0; i -= 6)
  {
    i2 = i / 2;
    start = HAL_GetTick();
    lcdFillRect(cx-i2, cy-i2, i, i, color1);
    t    += HAL_GetTick() - start;
    // Outlines are not included in timing results
    lcdDrawRect(cx-i2, cy-i2, i, i, color1);
  }

  return t;
}

unsigned long testFilledCircles(uint8_t radius, uint16_t color)
{
  unsigned long start;
  int x, y, w = lcdGetWidth(), h = lcdGetHeight(), r2 = radius * 2;

  lcdFillRGB(COLOR_BLACK);
  start = HAL_GetTick();
  for(x = radius; x < w; x += r2)
  {
    for(y = radius; y < h; y += r2)
    {
      lcdFillCircle(x, y, radius, color);
    }
  }

  return HAL_GetTick() - start;
}

unsigned long testCircles(uint8_t radius, uint16_t color)
{
  unsigned long start;
  int x, y, r2 = radius * 2,
      w = lcdGetWidth()  + radius,
      h = lcdGetHeight() + radius;

  // Screen is not cleared for this one -- this is
  // intentional and does not affect the reported time.
  start = HAL_GetTick();
  for(x = 0; x < w; x += r2)
  {
    for(y = 0; y < h; y += r2)
    {
      lcdDrawCircle(x, y, radius, color);
    }
  }

  return HAL_GetTick() - start;
}

unsigned long testTriangles()
{
  unsigned long start;
  int n, i, cx = lcdGetWidth() / 2 - 1,
            cy = lcdGetHeight() / 2 - 1;

  lcdFillRGB(COLOR_BLACK);
  n = min(cx, cy);
  start = HAL_GetTick();
  for(i = 0; i < n; i += 5)
  {
    lcdDrawTriangle(
      cx    , cy - i, // peak
      cx - i, cy + i, // bottom left
      cx + i, cy + i, // bottom right
      lcdColor565(i, i, i));
  }

  return HAL_GetTick() - start;
}

unsigned long testFilledTriangles()
{
  unsigned long start, t = 0;
  int i, cx = lcdGetWidth() / 2 - 1,
         cy = lcdGetHeight() / 2 - 1;

  lcdFillRGB(COLOR_BLACK);
  for(i = min(cx, cy); i > 10; i -= 5)
  {
    start = HAL_GetTick();
    lcdFillTriangle(cx, cy - i, cx - i, cy + i, cx + i, cy + i, lcdColor565(0, i*10, i*10));
    t += HAL_GetTick() - start;
    lcdFillTriangle(cx, cy - i, cx - i, cy + i, cx + i, cy + i, lcdColor565(i*10, i*10, 0));
  }

  return t;
}

unsigned long testRoundRects()
{
  unsigned long start;
  int w, i, i2,
      cx = lcdGetWidth() / 2 - 1,
      cy = lcdGetHeight() / 2 - 1;

  lcdFillRGB(COLOR_BLACK);
  w = lcdGetWidth(), lcdGetHeight();
  start = HAL_GetTick();
  for(i = 0; i < w; i += 6)
  {
    i2 = i / 2;
    lcdDrawRoundRect(cx-i2, cy-i2, i, i, i/8, lcdColor565(i, 0, 0));
  }

  return HAL_GetTick() - start;
}

unsigned long testFilledRoundRects()
{
  unsigned long start;
  int i, i2,
      cx = lcdGetWidth()  / 2 - 1,
      cy = lcdGetHeight() / 2 - 1;

  lcdFillRGB(COLOR_BLACK);
  start = HAL_GetTick();
  for(i = min(lcdGetWidth(), lcdGetHeight()); i > 20; i -=6 )
  {
    i2 = i / 2;
    lcdFillRoundRect(cx - i2, cy - i2, i, i, i / 8, lcdColor565(0, i, 0));
  }

  return HAL_GetTick() - start;
}

unsigned long testDrawImage()
{
	unsigned long start;

	lcdFillRGB(COLOR_BLACK);
	start = HAL_GetTick();
	if (lcdGetOrientation() == LCD_ORIENTATION_LANDSCAPE || lcdGetOrientation() == LCD_ORIENTATION_LANDSCAPE_MIRROR)
	{
		lcdDrawImage((lcdGetWidth() - bmSTLogo.xSize) / 2, 0, &bmSTLogo);
	}
	else
	{
		lcdDrawImage(0, (lcdGetHeight() - bmSTLogo.ySize) / 2, &bmSTLogo);
	}
	return HAL_GetTick() - start;
}
/* USER CODE END 4 */

/**
  * @brief  Period elapsed callback in non blocking mode
  * @note   This function is called  when TIM2 interrupt took place, inside
  * HAL_TIM_IRQHandler(). It makes a direct call to HAL_IncTick() to increment
  * a global variable "uwTick" used as application time base.
  * @param  htim : TIM handle
  * @retval None
  */
void HAL_TIM_PeriodElapsedCallback(TIM_HandleTypeDef *htim)
{
  if (htim->Instance == TIM2) {
    HAL_IncTick();
  }
}

/**
  * @brief  This function is executed in case of error occurrence.
  * @retval None
  */
void Error_Handler(void)
{
  /* USER CODE BEGIN Error_Handler_Debug */
  /* User can add his own implementation to report the HAL error return state */
  __disable_irq();
  while (1)
  {
  }
  /* USER CODE END Error_Handler_Debug */
}

#ifdef  USE_FULL_ASSERT
/**
  * @brief  Reports the name of the source file and the source line number
  *         where the assert_param error has occurred.
  * @param  file: pointer to the source file name
  * @param  line: assert_param error line source number
  * @retval None
  */
void assert_failed(uint8_t *file, uint32_t line)
{
  /* USER CODE BEGIN 6 */
  /* User can add his own implementation to report the file name and line number,
     ex: printf("Wrong parameters value: file %s on line %d\r\n", file, line) */
  /* USER CODE END 6 */
}
#endif /* USE_FULL_ASSERT */

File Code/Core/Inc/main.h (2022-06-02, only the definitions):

#define ENCODER0_REVERSE_Pin GPIO_PIN_2
#define ENCODER0_REVERSE_GPIO_Port GPIOE
#define ENCODER1_REVERSE_Pin GPIO_PIN_3
#define ENCODER1_REVERSE_GPIO_Port GPIOE
#define ENCODER2_REVERSE_Pin GPIO_PIN_13
#define ENCODER2_REVERSE_GPIO_Port GPIOC
#define TOUCH_CS_Pin GPIO_PIN_0
#define TOUCH_CS_GPIO_Port GPIOH
#define TOUCH_IRQ_Pin GPIO_PIN_1
#define TOUCH_IRQ_GPIO_Port GPIOH
#define SDCARD_CS_Pin GPIO_PIN_0
#define SDCARD_CS_GPIO_Port GPIOC
#define ANALOG0_Pin GPIO_PIN_0
#define ANALOG0_GPIO_Port GPIOA
#define ANALOG2_Pin GPIO_PIN_3
#define ANALOG2_GPIO_Port GPIOA
#define LED_LCD_ON_Pin GPIO_PIN_5
#define LED_LCD_ON_GPIO_Port GPIOA
#define ETH_RESET_Pin GPIO_PIN_0
#define ETH_RESET_GPIO_Port GPIOB
#define ANALOG1_Pin GPIO_PIN_1
#define ANALOG1_GPIO_Port GPIOB
#define INPUT2_Pin GPIO_PIN_2
#define INPUT2_GPIO_Port GPIOB
#define OUTPUT3_Pin GPIO_PIN_14
#define OUTPUT3_GPIO_Port GPIOB
#define OUTPUT2_Pin GPIO_PIN_15
#define OUTPUT2_GPIO_Port GPIOB
#define ENCODER2_M_Pin GPIO_PIN_12
#define ENCODER2_M_GPIO_Port GPIOD
#define ENCODER2_P_Pin GPIO_PIN_13
#define ENCODER2_P_GPIO_Port GPIOD
#define ENCODER0_M_Pin GPIO_PIN_8
#define ENCODER0_M_GPIO_Port GPIOA
#define ENCODER0_P_Pin GPIO_PIN_9
#define ENCODER0_P_GPIO_Port GPIOA
#define INPUT0_Pin GPIO_PIN_10
#define INPUT0_GPIO_Port GPIOA
#define INPUT1_Pin GPIO_PIN_15
#define INPUT1_GPIO_Port GPIOA
#define INPUT3_Pin GPIO_PIN_10
#define INPUT3_GPIO_Port GPIOC
#define LDAC_Pin GPIO_PIN_11
#define LDAC_GPIO_Port GPIOC
#define OUTPUT1_Pin GPIO_PIN_3
#define OUTPUT1_GPIO_Port GPIOD
#define OUTPUT0_Pin GPIO_PIN_6
#define OUTPUT0_GPIO_Port GPIOD
#define ENCODER1_M_Pin GPIO_PIN_4
#define ENCODER1_M_GPIO_Port GPIOB
#define ENCODER1_P_Pin GPIO_PIN_5
#define ENCODER1_P_GPIO_Port GPIOB
#define LCD_RESET_Pin GPIO_PIN_0
#define LCD_RESET_GPIO_Port GPIOE
#define CAMERA_RESET_Pin GPIO_PIN_1
#define CAMERA_RESET_GPIO_Port GPIOE

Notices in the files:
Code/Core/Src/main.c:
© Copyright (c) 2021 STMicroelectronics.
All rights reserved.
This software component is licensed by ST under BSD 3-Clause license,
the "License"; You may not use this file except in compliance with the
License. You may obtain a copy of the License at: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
